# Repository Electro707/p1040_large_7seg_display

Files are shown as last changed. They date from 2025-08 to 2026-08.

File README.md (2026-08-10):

# P1040 - Large 7-Segment Display Driver
\> PCBs (both), Rev 1
\> Firmware, WIP
\> Enclosure, WIP

This project is a driver for some large 4in 7-segment displays

Image of project

# Directory Structure
- `CAD`: All FreeCAD enclosure related stuff
    - C1045: Display Holder
    - C1046: Driver Board Holder, spans 2 displays
    - C1047: Single Display Backside
    - C1048: Dowel
- E1041: PCB, Driver board, KiCAD
- E1042: PCB, Pin to Connector Adapter, KiCAD
- F1043: A demo quick firmware for testing
- F1044: Main Firmware
- `misc`: Miscellaneous files. Right now only the spreadsheet I used for some calculations exists
- `release`: Latest exported build files, includes Schematic, BOM, Gerber, and STL files

# Known Issues
> [!IMPORTANT]
> Please read the file linked below before attempting to build this hardware.

Known issues, and any workarounds, are documented in [ERRATA.md](ERRATA.md)

# Firmware
For more info on the firmware, including building and programming, see [F1044/README.md](F1044/README.md)

# License
This project is licensed under [GPLv3](LICENSE.md)**

** This excludes the files in `E1041 - PCB, Driver Board/ExternalStep`, as they came from the manufacturer.
** Also excludes the files `zones.c` and `zones.h` in `F1044`, as those are modified from the [micro_tz_d library](https://github.com/jdlambert/micro_tz_db/tree/master) which is under an MIT license

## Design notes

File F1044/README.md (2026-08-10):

# F1044 Firmware

## Building
This firmware uses PlatformIO for it's build system.

You should be able to build either in VSCode, or in the CLI by running
```bash
pio run     # to build
pio run --target upload     # to upload
```

## Uploading
During the initial build, one must upload the firmware over the programming interface
on the E1041 PCB, J23 (next to the MCU). The pogo pins is for a [Tag-Connect](https://www.tag-connect.com/product/tc2030-idc-nl)
connector. The programming pinout is available on the schematic.

I personally used a generic ESP programmer dev board to upload the firmware, the one below is what I have.
Image of programmer

On that particular programmer, I connected the yellow header to the tag-connect it as follows:
|---------------|-----------------|
|ESP Programmer | Tag Connect Pin |
|---------------|-----------------|
|RX             |1                |
|TX             |2                |
|3V3            |3                |
|RST            |4                |
|IO0            |5                |
|GND            |6                |
|---------------|-----------------|

Then you can use esptool.py to upload the firmware.

After the initial firmware upload, while you can still use the tag-connect, the firmware also accepts new firmware
over the serial line. I build a python script [`tools/upload.py`](tools/upload.py) to accomplish this.

The first argument is the firmware bin file, the second is either an IP address or the serial port to upload over.

The uploading in PIO is setup to use that script. You can change the port used in [platformio.ini](platformio.ini).

> TODO: Have the config use the port given in VSCode.
> TODO: Have a seperate config that uses esptool to upload, same build settings

## Extra Documentation
The documentation for this project, mainly pertaining to the commands, is written in AsciiDoc, and uses Asciidoctor to generate a PDF or HTML page.

The docs can be built with:
```bash
asciidoctor "doc/F1044 Doc.adoc"        # for HTML
asciidoctor-pdf "doc/F1044 Doc.adoc"    # for PDF
```

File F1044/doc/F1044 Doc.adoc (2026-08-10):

= F1044 - Large 7-Seg Display Firmware
rev 1-dev

== Purpose
The purpose of this document is to describe the F1044 firmware's function and command set

== Functional Description
The F1044 firmware controls up to 8 7-segment displays. The displays are intended to be 4" displays.

NOTE: While the firmware can handle up to 8 displays as per hardware, it has only been tested for 6 displays, although
there is no reason it shouldn't work with 8.

=== Modes
This firmware has the following run-time modes:

* *off* : The displays are disabled, nothing is displayed
* *numb* : Shows a static number on the display. Useful for host updated numeric display
* *time*: Shows the current time based off the timezone set.

The default timezone is EDT (mine!), but can be changed with the `set timeZone` command

=== Time Format

When displaying time, this firmware can present that in the following modes:

* *24hr*: Displays the time as HH:MM in 24-hour format
* *12hr*: Displays the time as HH:MM in 12-hour format. No AM/PM indicator can be shown in this mode
* *metric*: Displays the time as HH:MM in metric format. See https://metric-time.com/ for more information on this format

=== NVM
This firmware stores some parameters in non-volatile memory (nvm). The esp32-arduino's `EEPROM` is used, handling data storage and integrity.
The following table describes what is stored.

[%autowidth]
|===
|Offset|Length|Type|Description

|0
|1
|byte
|NVM magic to check if something is written. Should be 0x5A

|1
|32
|str
|WIFI SSID to connect to

|33
|32
|str
|WIFI password to connect to

|===

=== Communication
This firmware is communicated with over the following interfaces:

* Serial over USB, 115200 baud, 8N1
* Ethernet or WiFi, telnet, port 23
* Ethernet or WiFi, ModBus, port 502 (IN PROGRESS)

All command frames sent to/from the device over serial or Telnet are in ASCII text mode, with either carriage-return (\r) or line-feed (\n) ending per frame.

If a command doesn't sent back a return value, an acknowledgment (ACK) may be sent back as the string "ok".
Any non-acknowledgments (NACK) may be sent as "error: X", where X is a human description of the error.

==== Ethernet, Telnet
This firmware handles being connected over Telnet directly, allowing to connect to this firmware over the built-in `telnet` command on many UNIX systems.

The following telnet commands (different than the commands on the firmware) are handled:

* DO
* WILL
* Interrupt Process, including waiting for timing-mark to responds with a new line and flush the internal receive buffer

This firmware also implements a "exit" command to close a Telnet connection.

[page-layout=landscape]
<<<

== Commands
The commands are structured as verb-noun system; the verb dictates the action, and noun is what to apply the verb to. For example "get mode" requests to "get" the "mode".
The verb and noun are space delimited. Any argument(s) to the command are also space delimited.

The following table list all the commands:

// [%autowidth]
[cols="1,2,5,5,6"]
|===
|Verb|Noun|Arguments|Return|Desc

|ping
|
|
|pong!
|ping-pong!

.8+|set
|mode
|[str], mode
|ACK
|Set the new mode, which is the same string as described in <<Modes>>

|n
|The number to display to in "numb" mode
|ACK, only if in "numb" mode
|

|timeFormat
a|[str], The new time format, either:

- '24hr'
- '12hr'
- 'metric'
|
|Sets the displayed time format, which is the same string as described in <<Time Format>>

|wifiSSID
|SSID
|
|Sets the WiFi SSID

|wifiPass
|password
|
|Sets the WiFi password

|wifiOff
|
|
|Turns wifi on if disabled and not running

|wifiOn
|password
|
|Turns wifi off if enabled and running

|timeZone
|The timezone as a TZ string. Use the command "get allTimeZones" to get valid timezones
|
|

.7+|get
|version
|
|The firmware version
|

|mode
|
|The current mode
|

|n
|
|The current displayed number
|

|timeFormat
|
|The time format
|See <<Time Format>>

|ip
|
|The current IP address of either Ethernet or Wifi, or "none" if not connected to the internet
|

|wifiInfo
|
|The current WiFi SSID and Password set
|

|allTimeZones
|
|All valid time zones
|

.4+|update
|begin
|The firmware size in bytes
|
|Starts a firmware update

|cont
|The number of bytes to send, then the raw bytes after reception of the first ACK
|ACK, followed by another ACK after raw bytes received
|When this command is received with the number of bytes to send, an ACK is sent. The firmware then expects
 that many bytes (not ASCII) to be received, in which another ACK will be sent after all expected bytes are received

|end
|
|
|Finishes the firmware update process

|cancel
|
|
|Cancels any on-going firmware update process

|saveNvm
|
|
|
|Saves the current NVM configuration

|exit
|
|
|
|In Telnet mode, this command sends the required Telnet commands to disconnect.

|reboot
|
|
|
|Reboots the microcontroller
|===

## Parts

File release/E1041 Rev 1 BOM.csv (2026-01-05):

Qty | DNP | Reference | Part Number | Description | Value | Footprint
1 |  | AE1 | 2450AT43F0100001E | Chip Antenna, 2.4Ghz | Antenna_Chip | RF_Antenna:Johanson_2450AT43F0100
4 |  | C1,C21,C22,C23 |  | Capacitor, 0.1uF, 0805 | 0.1u | Capacitor_SMD:C_0805_2012Metric
1 |  | C2 | 865060845002 | Capacitor, 10uF, 100V | 100uF | Capacitor_SMD:C_Elec_6.3x5.4
10 |  | C3,C5,C7,C8,C10,C13,C14,C15,C26,C29 |  |  | 0.1uF | Capacitor_SMD:C_0805_2012Metric,Capacitor_SMD:C_0805_2012Metric_Pad1.18x1.45mm_HandSolder
6 |  | C4,C16,C17,C18,C20,C28 |  |  | 1uF | Capacitor_SMD:C_0805_2012Metric,Capacitor_SMD:C_0805_2012Metric_Pad1.18x1.45mm_HandSolder,Capacitor_SMD:C_1206_3216Metric_Pad1.33x1.80mm_HandSolder
2 |  | C6,C12 |  |  | 22uF | Capacitor_SMD:C_1206_3216Metric_Pad1.33x1.80mm_HandSolder,Capacitor_SMD:C_Elec_6.3x5.4
2 |  | C9,C11 |  |  | 10uF | Capacitor_SMD:C_0805_2012Metric_Pad1.18x1.45mm_HandSolder,Capacitor_SMD:C_1206_3216Metric_Pad1.33x1.80mm_HandSolder
1 |  | C24 |  |  | 2.2pF | Capacitor_SMD:C_0603_1608Metric
1 |  | C25 |  |  | 4pF | Capacitor_SMD:C_0603_1608Metric
1 |  | C27 |  |  | 4.7uF | Capacitor_SMD:C_0805_2012Metric_Pad1.18x1.45mm_HandSolder
2 |  | D1,D2 | CDBHM220L |  | CDBHM220L | Package_TO_SOT_SMD:TO-269AA
1 |  | D3 | SMAJ58A |  | SMAJ58A | Diode_SMD:D_SMA
1 |  | D4 | SMF15A |  | SMF15A | Diode_SMD:D_SMF
2 |  | D5,D6 |  |  | LED | LED_SMD:LED_1206_3216Metric
4 |  | D7,D9,D10,D11 | MBR0530 |  | MBR0530 | Diode_SMD:D_SOD-123
2 |  | F1,F2 | 0ZCJ0050FF2G |  | 500mA | Fuse:Fuse_1206_3216Metric
1 |  | J1 | PJ-202A |  | Barrel_Jack | Connector_BarrelJack:BarrelJack_Horizontal
1 |  | J2 | 1751248 |  | Screw_Terminal_01x02 | TerminalBlock_Phoenix:TerminalBlock_Phoenix_MKDS-1,5-2-5.08_1x02_P5.08mm_Horizontal
1 |  | J3 | 74984104400 |  | 74984104400 | ProjectFootprints:74984104400
1 |  | J4 |  |  | Conn_Coaxial | Connector_Coaxial:SMA_Amphenol_901-143_Horizontal
1 |  | J5 |  |  | Conn_01x03 | Connector_PinSocket_2.54mm:PinSocket_1x03_P2.54mm_Vertical
1 |  | J6 | USB4105-GF-A |  | USB_C_Receptacle_USB2.0_14P | Connector_USB:USB_C_Receptacle_GCT_USB4105-xx-A_16P_TopMnt_Horizontal
16 |  | J7,J8,J9,J10,J11,J12,J13,J14,J15,J16,J17,J18,J19,J20,J21,J22 | B5B-PH-K-S |  | Conn_01x05_Pin | Connector_JST:JST_PH_B5B-PH-K_1x05_P2.00mm_Vertical
1 |  | J23 |  |  | Conn_01x06_Female | Connector:Tag-Connect_TC2030-IDC-NL_2x03_P1.27mm_Vertical
1 |  | JP1 |  | Resistor Jumper, 0805 | Jumper_2_Bridged | Resistor_SMD:R_0805_2012Metric
3 |  | L1,L3,L4 | BLM21AG102SN1D | Ferrite Bead | L_Ferrite | Inductor_SMD:L_0805_2012Metric
1 |  | L2 | MAMK2520T3R3M | Inductor, 3.3uH, 1206 | 3.3uH | Inductor_SMD:L_1206_3216Metric_Pad1.22x1.90mm_HandSolder
1 |  | L5 | L-14C2N2SV4T | Inductor, 2.2nH, 0603 | 2.2nH | Inductor_SMD:L_0603_1608Metric
1 |  | L6 | 1239AS-H-6R8M=P2 | Inductor, 6.8uH, 1206 | 6.8uH | Inductor_SMD:L_1206_3216Metric_Pad1.22x1.90mm_HandSolder
1 |  | Q1 | MMBT3904 | NPN Transistor, SOT23 | MMBT3904 | Package_TO_SOT_SMD:SOT-23
1 |  | R1 |  | Resistor, 13k, 0805 | 13k | Resistor_SMD:R_0805_2012Metric
1 |  | R2 |  | Resistor, 12k, 0805 | 12k | Resistor_SMD:R_0805_2012Metric
1 |  | R3 |  | Resistor, 1.3k, 0805 | 1.3k | Resistor_SMD:R_0805_2012Metric
18 |  | R4,R7,R25,R26,R27,R36,R37,R38,R39,R40,R41,R42,R45,R46,R51,R52,R53,R54 |  | Resistor Jumper, 0805 | 0 | Resistor_SMD:R_0603_1608Metric,Resistor_SMD:R_0805_2012Metric
1 |  | R5 |  |  | 63.4 | Resistor_SMD:R_0805_2012Metric
1 |  | R6 |  |  | 249 | Resistor_SMD:R_0805_2012Metric
1 |  | R8 |  |  | 49.9k | Resistor_SMD:R_0805_2012Metric
3 | DNP | R9,R17,R33 |  |  | 0 | Resistor_SMD:R_0805_2012Metric
1 | DNP | R10 |  |  | DNP | Resistor_SMD:R_0805_2012Metric
1 |  | R11 |  |  | 470 | Resistor_SMD:R_0603_1608Metric_Pad0.98x0.95mm_HandSolder
9 |  | R12,R13,R23,R28,R29,R30,R48,R49,R50 |  |  | 10k | Resistor_SMD:R_0805_2012Metric,Resistor_SMD:R_0805_2012Metric_Pad1.20x1.40mm_HandSolder
1 |  | R14 |  |  | 31.6k | Resistor_SMD:R_0805_2012Metric_Pad1.20x1.40mm_HandSolder
5 |  | R15,R16,R24,R31,R32 |  |  | 1k | Resistor_SMD:R_0805_2012Metric,Resistor_SMD:R_0805_2012Metric_Pad1.20x1.40mm_HandSolder
4 |  | R18,R19,R20,R21 |  |  | 49.9 | Resistor_SMD:R_0805_2012Metric
1 |  | R22 |  |  | 12.1k | Resistor_SMD:R_0805_2012Metric
2 |  | R34,R35 |  |  | 5.1k | Resistor_SMD:R_0805_2012Metric
1 |  | R43 |  |  | 330 | Resistor_SMD:R_0805_2012Metric
1 |  | R44 |  |  | R | Resistor_SMD:R_0805_2012Metric
1 |  | R47 |  |  | 80.6k | Resistor_SMD:R_0805_2012Metric_Pad1.20x1.40mm_HandSolder
1 |  | U1 | TPS2372 |  | TPS2372 | ProjectFootprints:TI_RGW0020B
1 |  | U3 | AP62200WU-7 |  | AP62200WU-7 | Package_TO_SOT_SMD:TSOT-23-6
1 |  | U4 | LAN8720A |  | LAN8720A | Package_DFN_QFN:VQFN-24-1EP_4x4mm_P0.5mm_EP2.5x2.5mm_ThermalVias
1 |  | U5 | ESP32-PICO-D4 |  | ESP32-PICO-D4 | Package_DFN_QFN:QFN-48-1EP_7x7mm_P0.5mm_EP5.3x5.3mm
1 |  | U6 | CH340N |  | CH340N | Package_SO:SOP-8_3.9x4.9mm_P1.27mm
1 |  | U7 | STP08DP05 |  | STP08DP05 | Package_SO:SO-16_3.9x9.9mm_P1.27mm
1 |  | U8 | TBD62783A |  | TBD62783A | Package_SO:SOP-18_7x12.5mm_P1.27mm
1 |  | U9 | 74HC595 |  | 74HC595 | Package_SO:SO-16_3.9x9.9mm_P1.27mm
1 |  | U10 | TPS61040DBV |  | TPS61040DBV | Package_TO_SOT_SMD:SOT-23-5
1 |  | U11 | VCB4812SO-3WR3 |  | VCB48_SO-3WR3 | ProjectFootprints:VCB48_SO-3WR3
1 |  | X1 | ECS-2520MV-250-CN-TR |  | ECS-2520MV-xxx-xx | Oscillator:Oscillator_SMD_ECS_2520MV-xxx-xx-4Pin_2.5x2.0mm

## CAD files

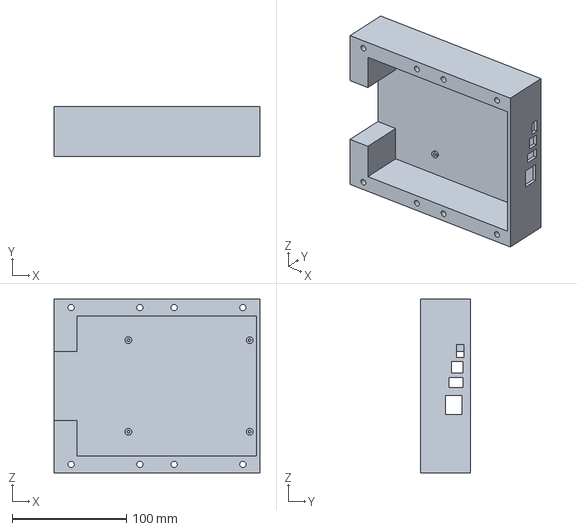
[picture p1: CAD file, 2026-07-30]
CAD/C1046.FCStd
180.0 x 44.0 x 152.0 mm

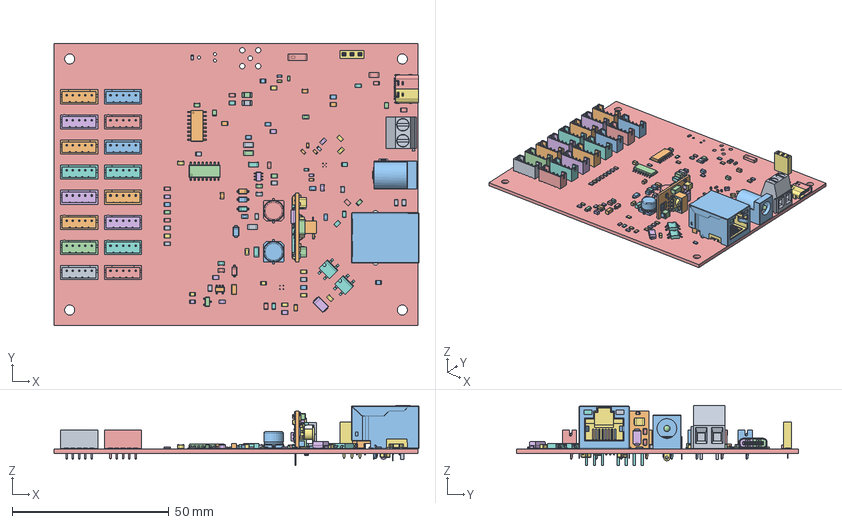
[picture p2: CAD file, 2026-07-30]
CAD/E1041 Rev 1.FCStd
116.3 x 90.0 x 19.2 mm
R_0805_2012Metric
JST_PH_B5B-PH-K_1x05_P2.00mm_Vertical
C_0603_1608Metric
C_0805_2012Metric
C_0805_2012Metric001
R_0805_2012Metric001
PinSocket_1x03_P2.54mm_Vertical
R_0805_2012Metric002
R_0805_2012Metric003
SOT-23-5
C_0805_2012Metric002
R_0805_2012Metric004
R_0805_2012Metric005
JST_PH_B5B-PH-K_1x05_P2.00mm_Vertical001
R_0805_2012Metric006
JST_PH_B5B-PH-K_1x05_P2.00mm_Vertical002
Fuse_1206_3216Metric
JST_PH_B5B-PH-K_1x05_P2.00mm_Vertical003
D_SOD-123
C_0805_2012Metric003
R_0805_2012Metric007
C_0805_2012Metric004
C_0805_2012Metric005
TO-269AA
C_1206_3216Metric
E1041 1.26.1
E1041 1.26.002
E1041 1.26.003
E1041 1.26.004
E1041 1.26.005
E1041 1.26.006
E1041 1.26.007
E1041 1.26.008
E1041 1.26.009
E1041 1.26.010
E1041 1.26.011
E1041 1.26.012
E1041 1.26.013
E1041 1.26.014
E1041 1.26.015
E1041 1.26.016
E1041 1.26.017
E1041 1.26.018
E1041 1.26.019
E1041 1.26.020
E1041 1.26.021
E1041 1.26.022
E1041 1.26.023
E1041 1.26.024
E1041 1.26.025
E1041 1.26.026
E1041 1.26.027
E1041 1.26.028
E1041 1.26.029
E1041 1.26.030
E1041 1.26.031
E1041 1.26.032
E1041 1.26.033
E1041 1.26.034
E1041 1.26.035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

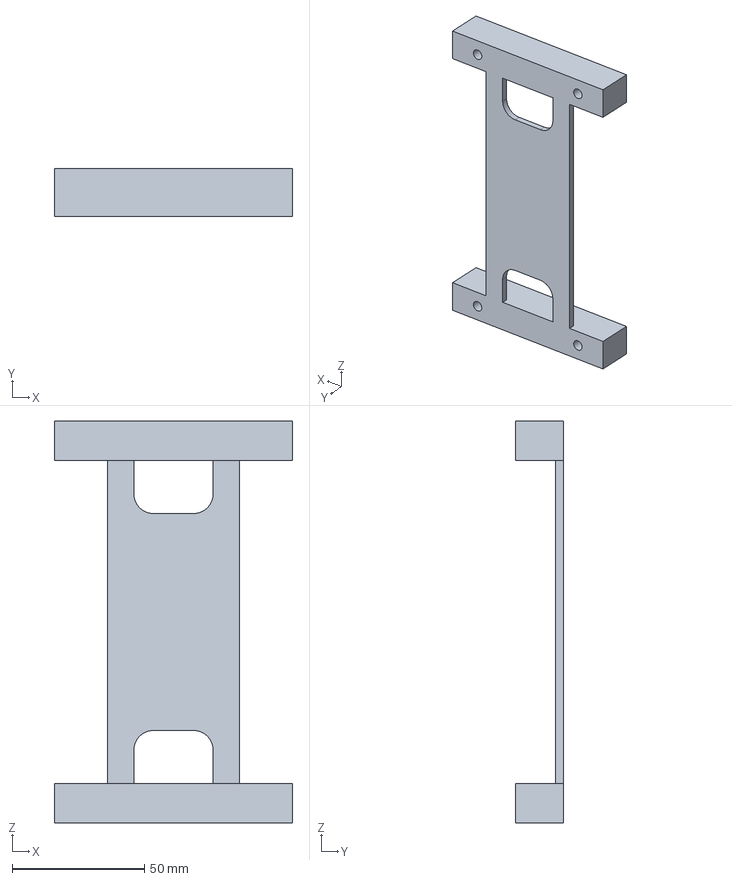
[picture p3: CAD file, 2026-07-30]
CAD/C1045.FCStd
90.0 x 18.0 x 152.0 mm

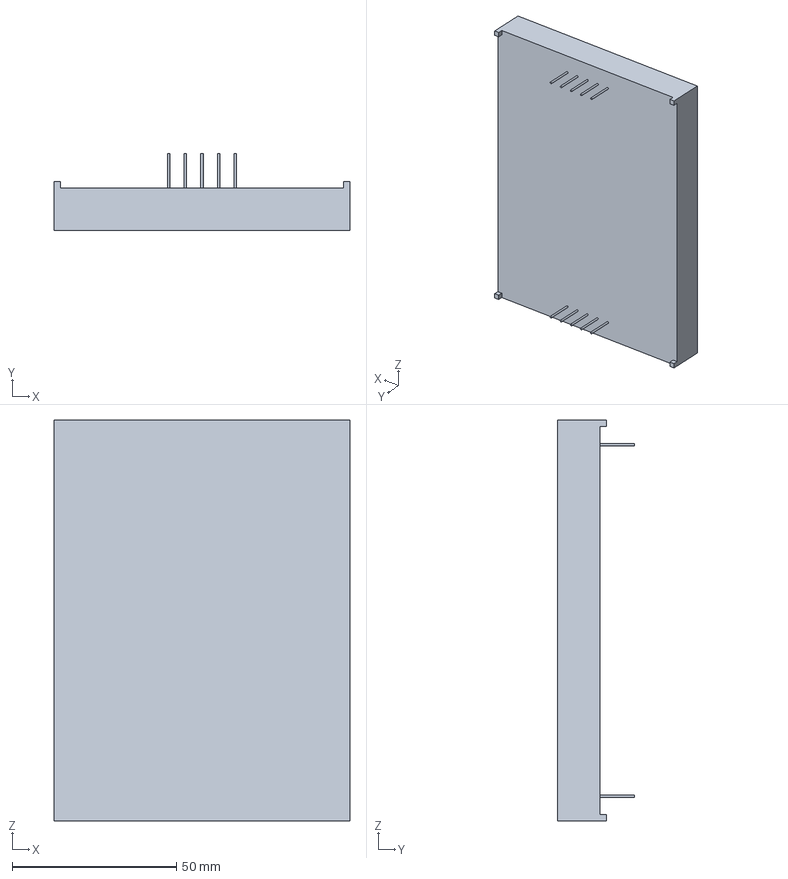
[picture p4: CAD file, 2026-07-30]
CAD/DisplaySingle.FCStd
90.0 x 23.5 x 122.0 mm

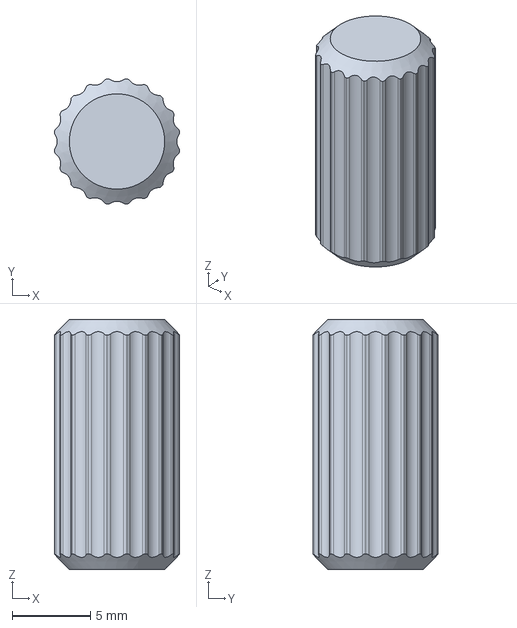
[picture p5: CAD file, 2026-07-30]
CAD/C1048.FCStd
8.01 x 8.01 x 16.0 mm

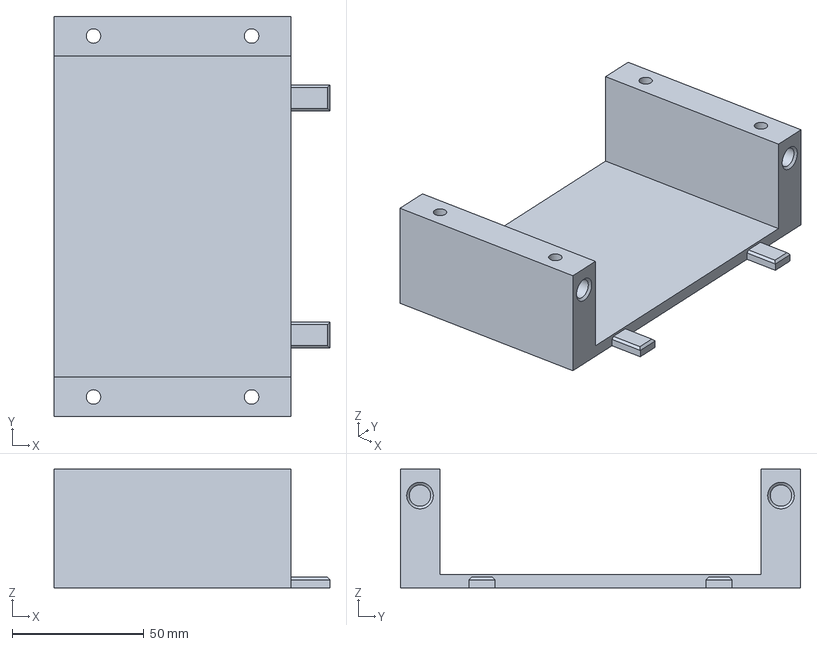
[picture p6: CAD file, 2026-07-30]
CAD/C1047.FCStd
104.8 x 152.0 x 45.0 mm

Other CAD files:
CAD/Assy.FCStd

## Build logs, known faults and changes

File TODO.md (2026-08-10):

# TODO

This is a TODO list for the next PCB revision

- Fix everything in errata
- Add reset button
- Add jumper or button to be able to jump to download mode
- Add test points
    - Some extra debug pads
    - For VCC and 12V as headers (for easy debugging, especially 5v for powerKit)
- Have it so SMA footprint comes out the back or top of enclosure (preferably the top)
- Shorten antenna routing to ensure less than 0.1 lambda of 2.4Gh
- [OPTIONAL] See if one can improve routing for ethernet portion to allow for 100M connection, right now limited to 10M, without going to 4 layer PCB
- Use the CH340 option with reset broken out to allow USB to reset ESP32, useful for uploading firmware as well
- Reduce resistance of dot segment, currently are too dim

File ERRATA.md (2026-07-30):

# Purpose
This document describes the hardware erratas and any potential fix using said hardware.

# E1041 Rev 1: Driver Board

## Errata 1: Crystal Enable
This issue is caused by a pull-up resistor on the enable line, which should be set as a pull-down to disable the crystal unless explicitly enabled by the MCU.

### Fix
For X1, have the pull-up resistor only soldered to the left pad (looking at the board up), then wire a short jumper between it and the nearby pad of the bypass capacitor to tie it to GND. See below:

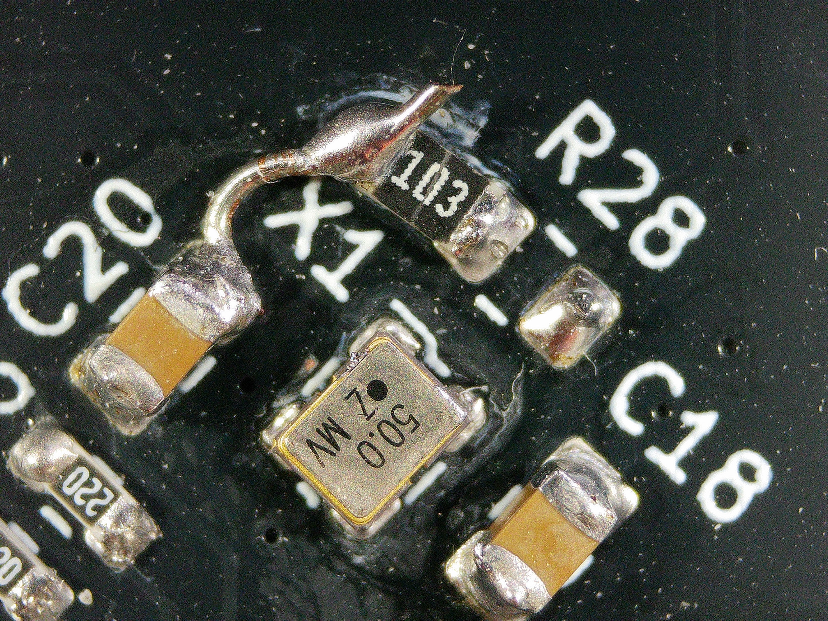
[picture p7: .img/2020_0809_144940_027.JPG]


## Errata 2: 50Mhz clock going to programming line
This issue is caused by GPIO0, which is both one of the programming lines and the 50Mhz Ethernet clock, being broken out to the programming header, which can cause signal integrity issue

### Fix
Either or both:
- Add a 1Kohm resistor in series between the programming line and GPIO0, as shown below
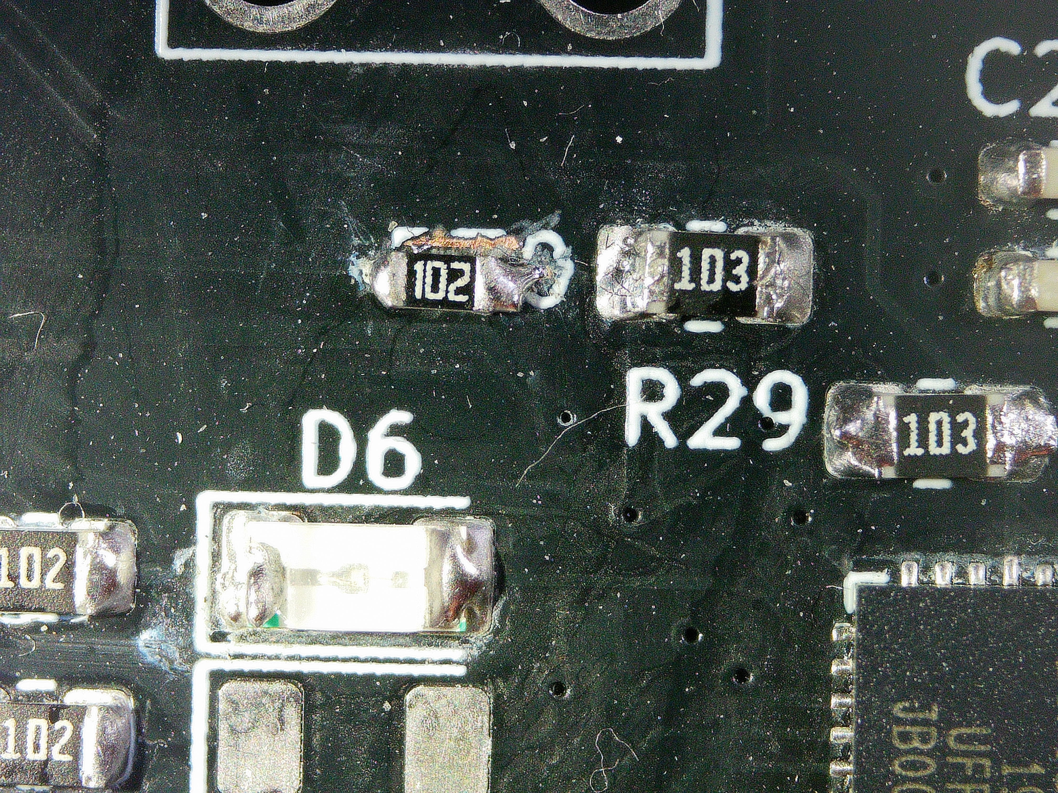
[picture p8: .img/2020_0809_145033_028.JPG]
    - 
- Remove the programming connector as soon as you are finished programming. Even with the previous fix, there is still enough signal integrity issue

## Errata 3: 100M Ethernet Connection Issue
The Ethernet Phy fails to establish a connection with the ESP32 when running in the default 10/100M mode in esp32's ethernet library.
This is presumably caused by bad signal integrity due to 2-layer design, among other factors.

### Fix
In software reducing the Ethernet to 10M only seems to fix this.

## Errata 4: Supplying with only 5v over USB

When only USB power is supplied, the device periodically restarts

### Investigation Notes
- When proving 5v on USB, there is a spike on the uS scale to ~1v. This tells me this is getting loaded down somehow
- It is random when, from power on, the device restarts. Sometimes instant, sometimes several seconds before the next restart. This tells me I am operating right on the edge of failure/working
- When supplying the 12V barrel jack with 12V, I don't see a USB dropout issue. This tells me the 5/12v to 3.3v converter is OK, most likely problem is the 12V generation
- Suspecting it might be something to do with the 5v to 12v boost converter section

### Fix
Root cause awaiting, TODO

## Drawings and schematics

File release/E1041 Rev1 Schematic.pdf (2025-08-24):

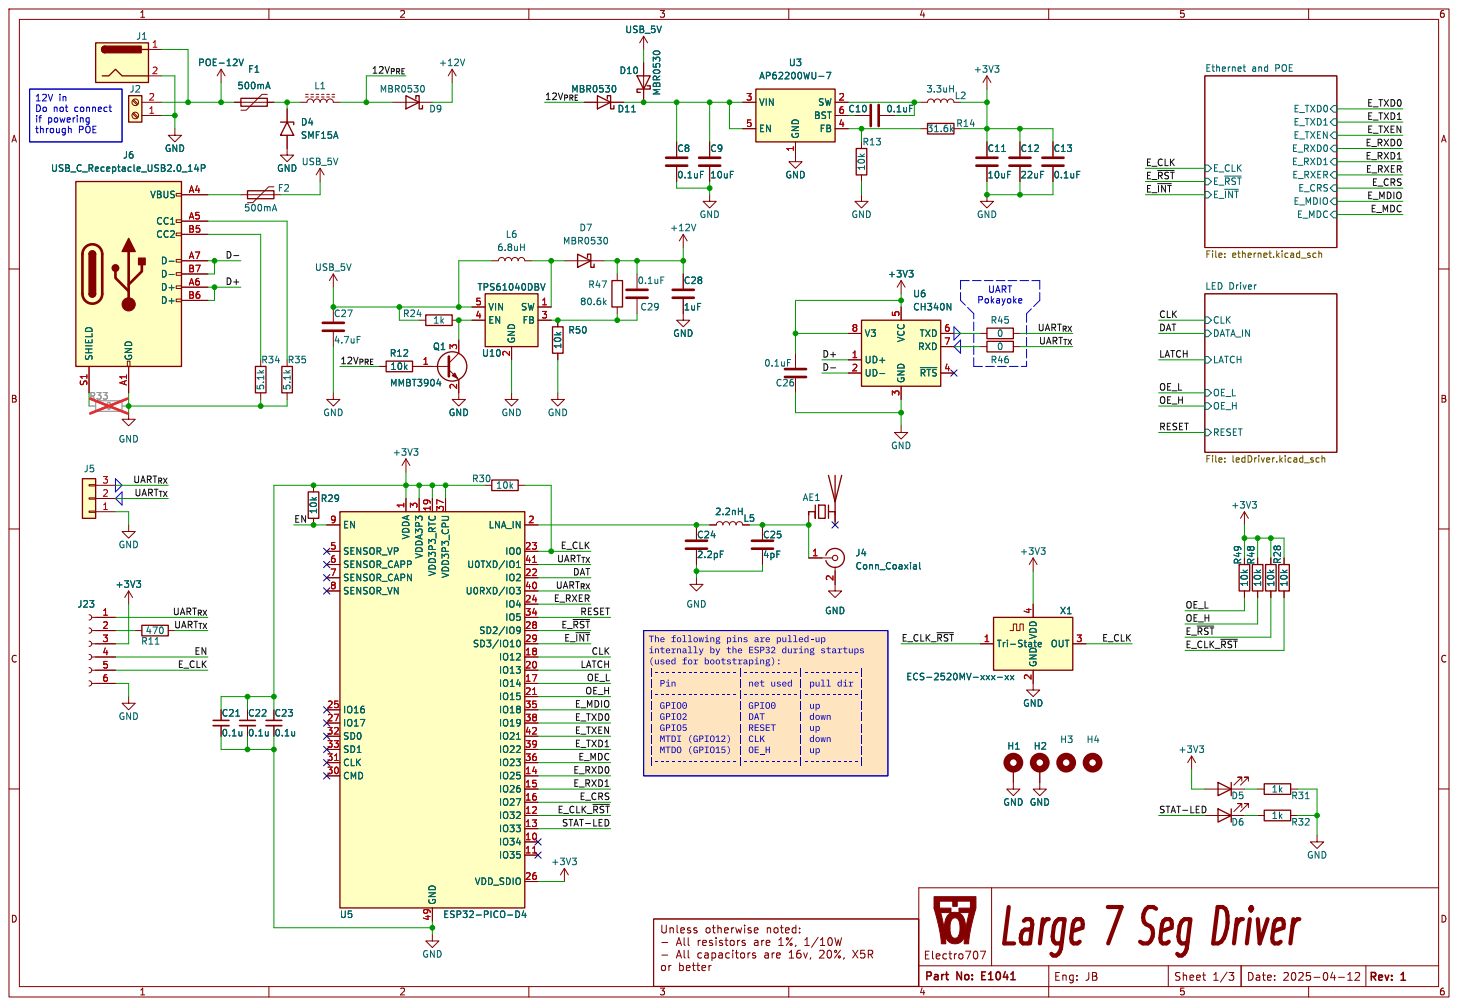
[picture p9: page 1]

12V in Do not connect

1 SW 2 BST 6 FB 4 GND GND

2 OUT 3 X1 ECS-2520MV-xxx-xx H3

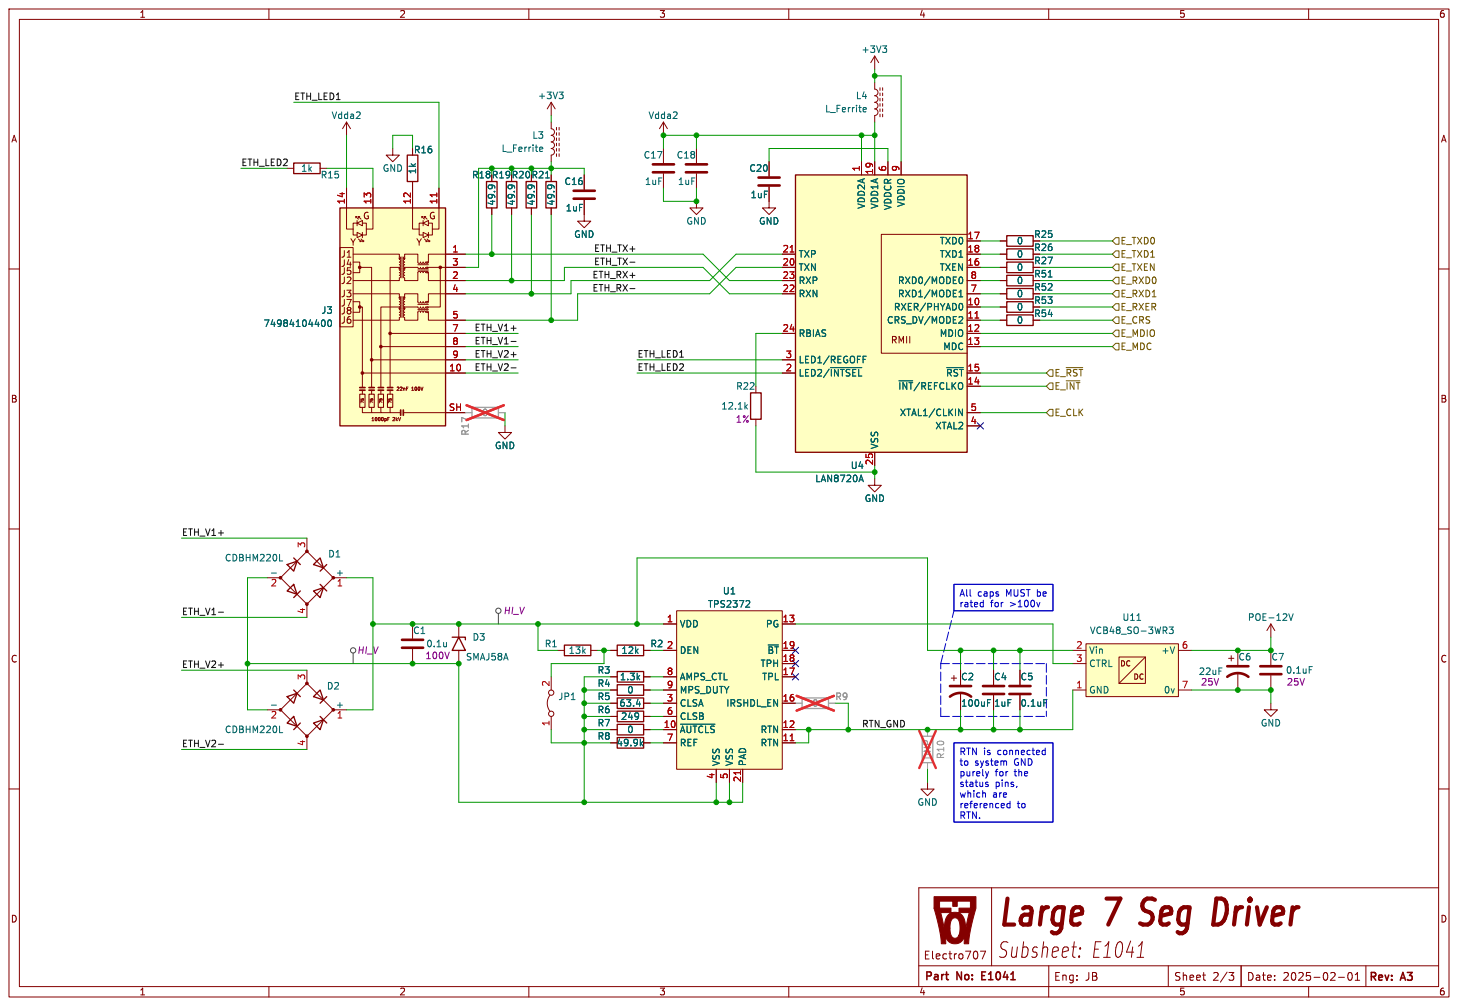
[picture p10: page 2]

1 TXP 21 TXN 20 RXP 23 RXN 22 RBIAS 24

5 PAD 21 PG 13 ~{BT} 19 TPH 18 TPL 17

to system GND
purely for the
status pins, which are

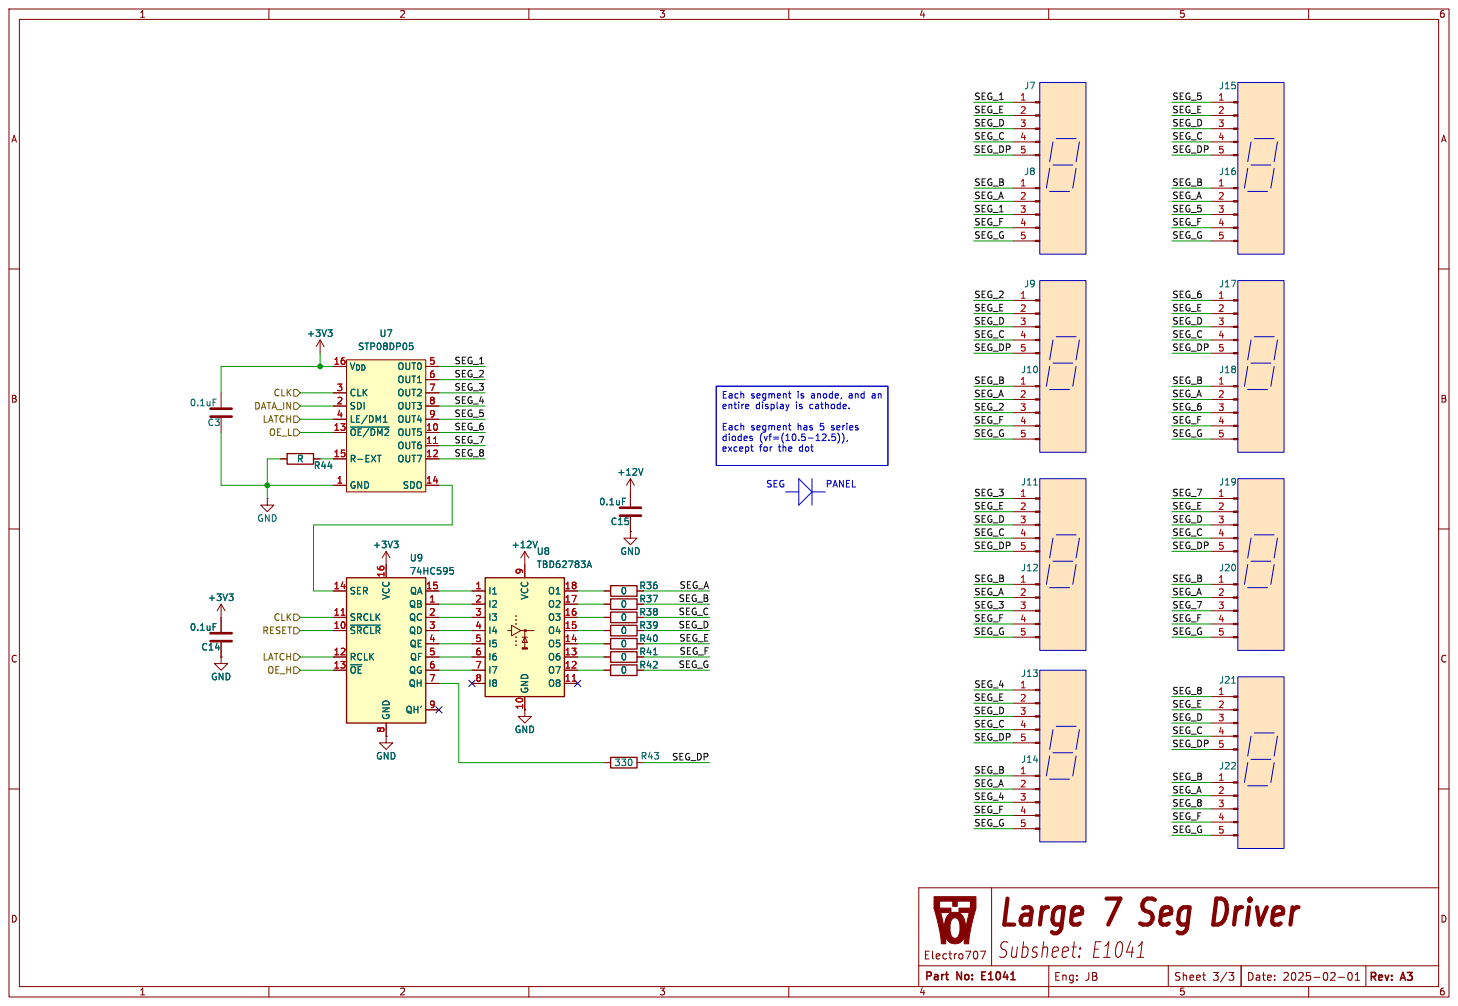
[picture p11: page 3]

Each segment is anode, and an

8 QA 15 QB 1 QC 2 QD 3 QE 4 QF 5 QG 6 QH 7 QH' 9 +3V3 +3V3 GND

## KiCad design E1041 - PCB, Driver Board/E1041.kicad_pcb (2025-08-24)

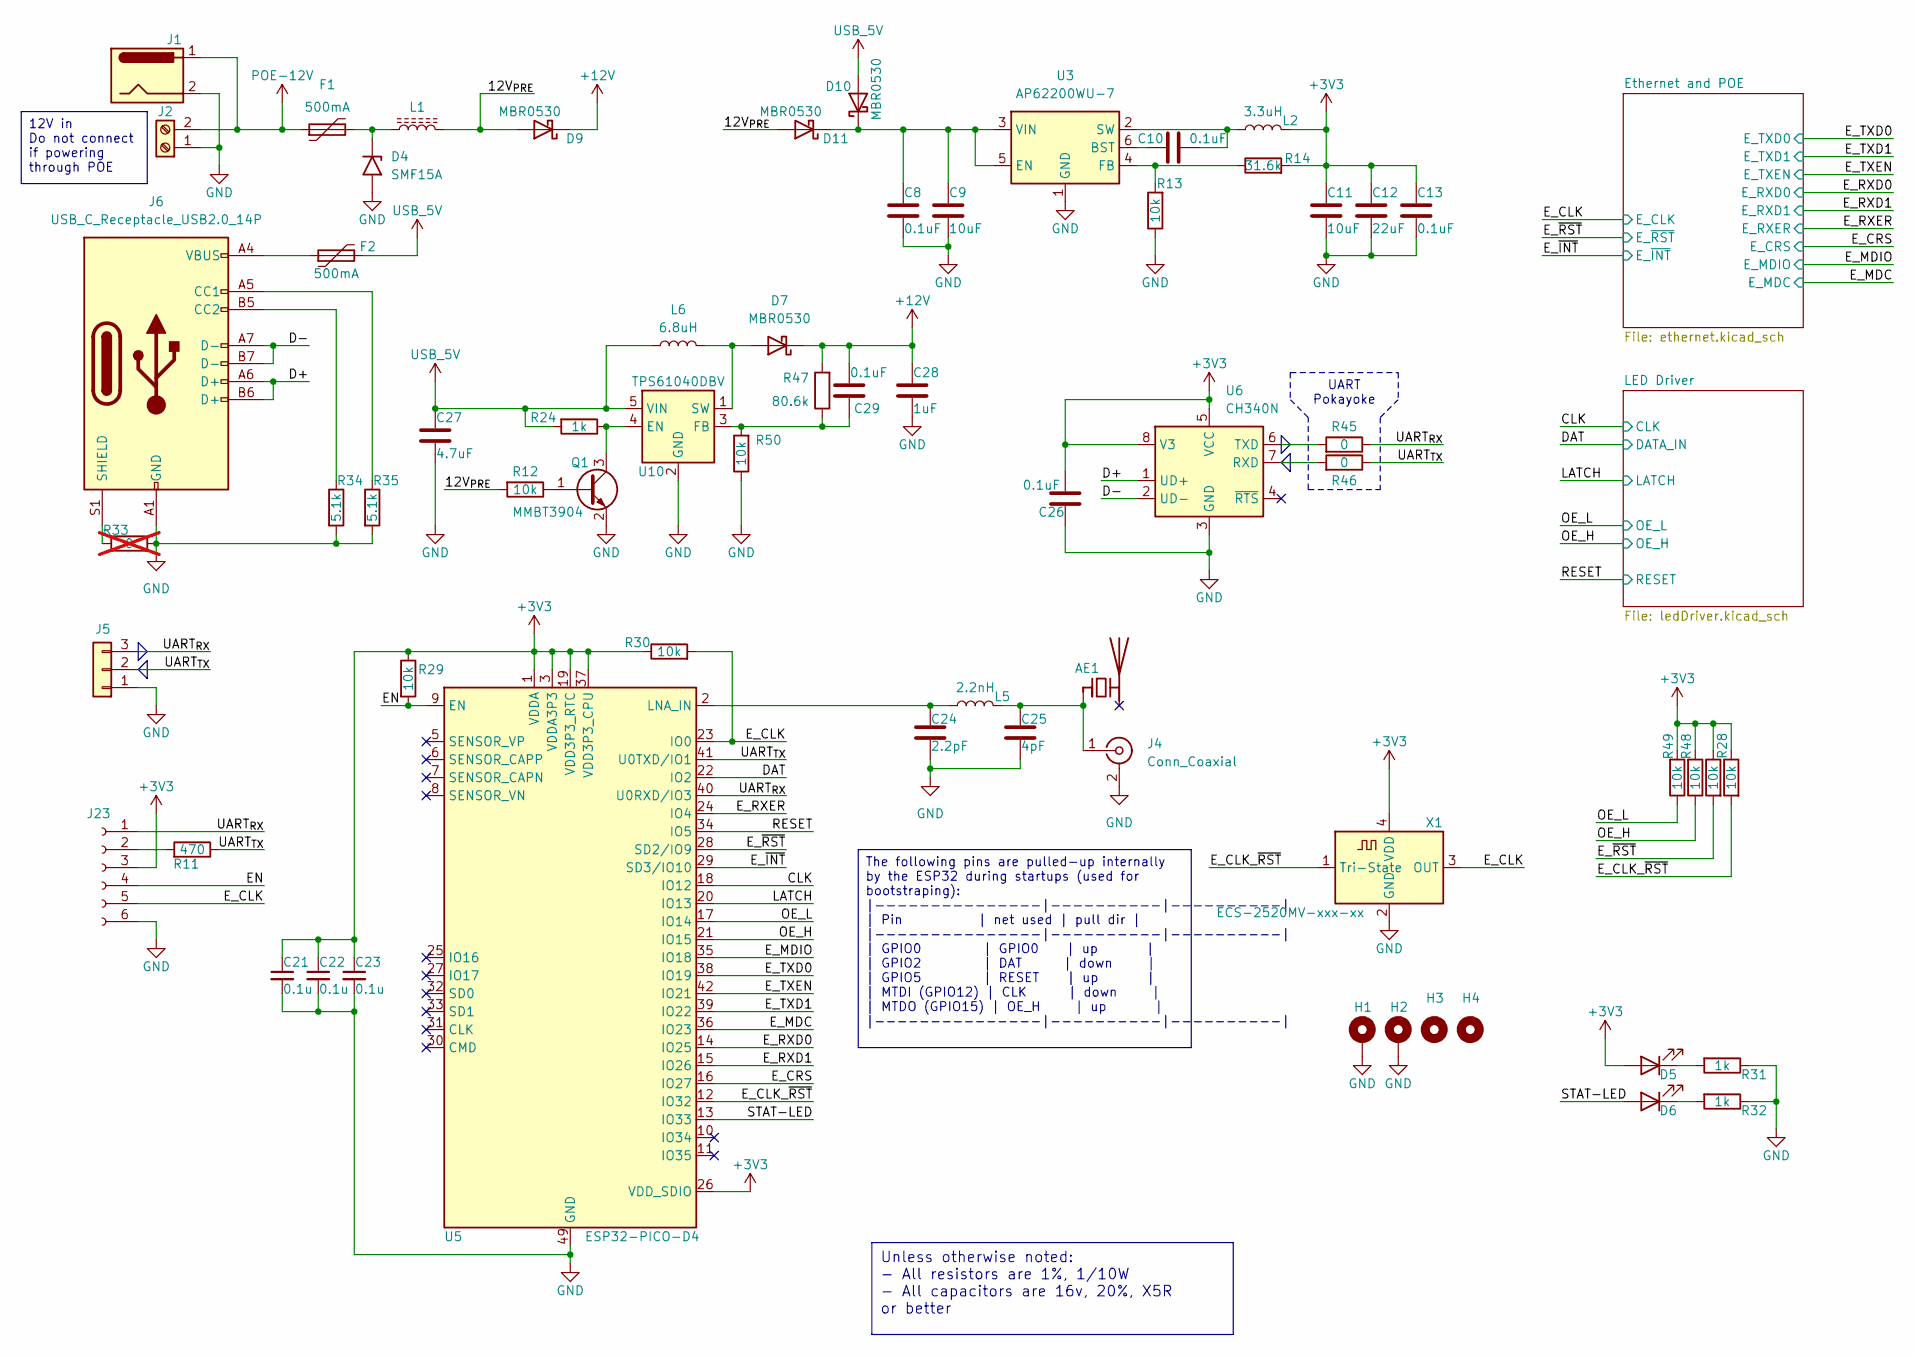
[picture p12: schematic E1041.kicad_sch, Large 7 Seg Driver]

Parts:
AE1: Antenna_Chip; Johanson_2450AT43F0100
C8, C10: 0.1uF; C_0805_2012Metric_Pad1.18x1.45mm_HandSolder
C9: 10uF; C_0805_2012Metric_Pad1.18x1.45mm_HandSolder
C11: 10uF; C_1206_3216Metric_Pad1.33x1.80mm_HandSolder
C12: 22uF; C_1206_3216Metric_Pad1.33x1.80mm_HandSolder
C13, C26, C29: 0.1uF; C_0805_2012Metric
C21, C22, C23: 0.1u; C_0805_2012Metric
C24: 2.2pF; C_0603_1608Metric
C25: 4pF; C_0603_1608Metric
C27: 4.7uF; C_0805_2012Metric_Pad1.18x1.45mm_HandSolder
C28: 1uF; C_0805_2012Metric_Pad1.18x1.45mm_HandSolder
D4: SMF15A; D_SMF
D5, D6: LED; LED_1206_3216Metric
D7, D9, D10, D11: MBR0530; D_SOD-123
F1, F2: 500mA; Fuse_1206_3216Metric
H1, H2: MountingHole_Pad; MountingHole_3.2mm_M3_DIN965_Pad
H3, H4: MountingHole_Pad; MountingHole_3.2mm_M3_DIN965
J1: Barrel_Jack; BarrelJack_Horizontal
J2: Screw_Terminal_01x02; TerminalBlock_Phoenix_MKDS-1,5-2-5.08_1x02_P5.08mm_Horizont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
J4: Conn_Coaxial; SMA_Amphenol_901-143_Horizontal
J5: Conn_01x03; PinSocket_1x03_P2.54mm_Vertical
J6: USB_C_Receptacle_USB2.0_14P; USB_C_Receptacle_GCT_USB4105-xx-A_16P_TopMnt_Horizontal
J23: Conn_01x06_Female; Tag-Connect_TC2030-IDC-NL_2x03_P1.27mm_Vertical
L1: L_Ferrite; L_0805_2012Metric
L2: 3.3uH; L_1206_3216Metric_Pad1.22x1.90mm_HandSolder
L5: 2.2nH; L_0603_1608Metric
L6: 6.8uH; L_1206_3216Metric_Pad1.22x1.90mm_HandSolder
Q1: MMBT3904; SOT-23
R11: 470; R_0603_1608Metric_Pad0.98x0.95mm_HandSolder
R12, R13, R29, R30, R50: 10k; R_0805_2012Metric_Pad1.20x1.40mm_HandSolder
R14: 31.6k; R_0805_2012Metric_Pad1.20x1.40mm_HandSolder
R23, R28, R48, R49: 10k; R_0805_2012Metric
R24: 1k; R_0805_2012Metric_Pad1.20x1.40mm_HandSolder
R31, R32: 1k; R_0805_2012Metric
R33: 0; R_0805_2012Metric; not fitted
R34, R35: 5.1k; R_0805_2012Metric
R45, R46: 0; R_0805_2012Metric
R47: 80.6k; R_0805_2012Metric_Pad1.20x1.40mm_HandSolder
U3: AP62200WU-7; TSOT-23-6
U5: ESP32-PICO-D4; QFN-48-1EP_7x7mm_P0.5mm_EP5.3x5.3mm
U6: CH340N; SOP-8_3.9x4.9mm_P1.27mm
U10: TPS61040DBV; SOT-23-5
X1: ECS-2520MV-xxx-xx; Oscillator_SMD_ECS_2520MV-xxx-xx-4Pin_2.5x2.0mm

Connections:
+3V3: C11.1, C12.1, C13.1, C21.1, C22.1, C23.1, C26.2, D5.2 (A), J23.3, L2.2, R14.2, R23.1, R28.1, R29.1, R30.1, R48.2, R49.2, U5.1 (VDDA), U5.3 (VDDA3P3), U5.4 (VDDA3P3), U5.19 (VDD3P3_RTC), U5.26 (VDD_SDIO), U5.37 (VDD3P3_CPU), U5.43 (VDDA), U5.46 (VDDA), U6.5 (VCC), U6.8 (V3), X1.4 (VDD); also elsewhere on the board
+12V: C28.1, C29.2, D7.1 (K), D9.1 (K), R47.2; also elsewhere on the board
/12V_{PRE}: D9.2 (A), D11.2 (A), L1.2, R12.2
/CLK: U5.18 (IO12); also elsewhere on the board
/D+: J6.A6 (D+), J6.B6 (D+), U6.1 (UD+)
/D-: J6.A7 (D-), J6.B7 (D-), U6.2 (UD-)
/DAT: U5.22 (IO2); also elsewhere on the board
/EN: J23.4, R29.2, U5.9 (EN)
/E_CLK: J23.5, R30.2, U5.23 (IO0), X1.3 (OUT); also elsewhere on the board
/E_CLK_~RST: R28.2, U5.12 (IO32), X1.1 (Tri-State)
/E_CRS: U5.16 (IO27); also elsewhere on the board
/E_MDC: U5.36 (IO23); also elsewhere on the board
/E_MDIO: U5.35 (IO18); also elsewhere on the board
/E_RXD0: U5.14 (IO25); also elsewhere on the board
/E_RXD1: U5.15 (IO26); also elsewhere on the board
/E_RXER: U5.24 (IO4); also elsewhere on the board
/E_TXD0: U5.38 (IO19); also elsewhere on the board
/E_TXD1: U5.39 (IO22); also elsewhere on the board
/E_TXEN: U5.42 (IO21); also elsewhere on the board
/E_~INT: U5.29 (SD3/IO10); also elsewhere on the board
/E_~RST: R23.2, U5.28 (SD2/IO9); also elsewhere on the board
/LATCH: U5.20 (IO13); also elsewhere on the board
/OE_H: R48.1, U5.21 (IO15); also elsewhere on the board
/OE_L: R49.1, U5.17 (IO14); also elsewhere on the board
/RESET: U5.34 (IO5); also elsewhere on the board
/STAT-LED: D6.2 (A), U5.13 (IO33)
/UART_{RX}: J5.3, J23.1, R45.1, U5.40 (U0RXD/IO3)
/UART_{TX}: J5.2, R11.1, R46.1, U5.41 (U0TXD/IO1)
GND: C8.2, C9.2, C11.2, C12.2, C13.2, C21.2, C22.2, C23.2, C24.2, C25.2, C26.1, C27.2, C28.2, D4.2 (A2), H1.1, H2.1, J1.2, J2.1, J4.2 (Ext), J5.1, J6.A1 (GND), J6.A12 (GND), J6.B1 (GND), J6.B12 (GND), J23.6, Q1.2 (E), R13.1, R31.1, R32.1, R33.2, R34.2, R35.2, R50.1, U3.1 (GND), U5.49 (GND), U6.3 (GND), U10.2 (GND), X1.2 (GND); also elsewhere on the board
unnamed: AE1.1 (FEED), C25.1, J4.1 (In), L5.2
unnamed: D4.1 (A1), F1.2, L1.1
unnamed: D5.1 (K), R31.2
unnamed: D6.1 (K), R32.2
unnamed: D7.2 (A), L6.2, U10.1 (SW)
unnamed: C8.1, C9.1, D10.1 (K), D11.1 (K), U3.3 (VIN), U3.5 (EN)
unnamed: F2.1, J6.A4 (VBUS), J6.A9 (VBUS), J6.B4 (VBUS), J6.B9 (VBUS)
unnamed: J6.A5 (CC1), R35.1
unnamed: J6.B5 (CC2), R34.1
unnamed: J6.S1 (SHIELD), R33.1
unnamed: J23.2, R11.2
unnamed: Q1.1 (B), R12.1
unnamed: Q1.3 (C), R24.1, U10.4 (EN)
unnamed: C10.1, U3.6 (BST)
unnamed: R13.2, R14.1, U3.4 (FB)
unnamed: C10.2, L2.1, U3.2 (SW)
unnamed: C24.1, L5.1, U5.2 (LNA_IN)
unnamed: R46.2, U6.7 (RXD)
unnamed: R45.2, U6.6 (TXD)
unnamed: C29.1, R47.1, R50.2, U10.3 (FB)
POE-12V: F1.1, J1.1, J2.2; also elsewhere on the board
USB_5V: C27.1, D10.2 (A), F2.2, L6.1, R24.2, U10.5 (VIN)

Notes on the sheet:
The following pins are pulled-up internally by the ESP32 during startups (used for bootstraping): |---------------|----------|----------| | Pin | net used | pull dir | |---------------|----------|----------| | GPIO0 | GPIO0 | up | | GPIO2 | DAT | down | | GPIO5 | RESET | up | | MTDI (GPIO12) | CLK 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
UART Pokayoke
12V in Do not connect if powering through POE
Unless otherwise noted: - All resistors are 1%, 1/10W - All capacitors are 16v, 20%, X5R or better

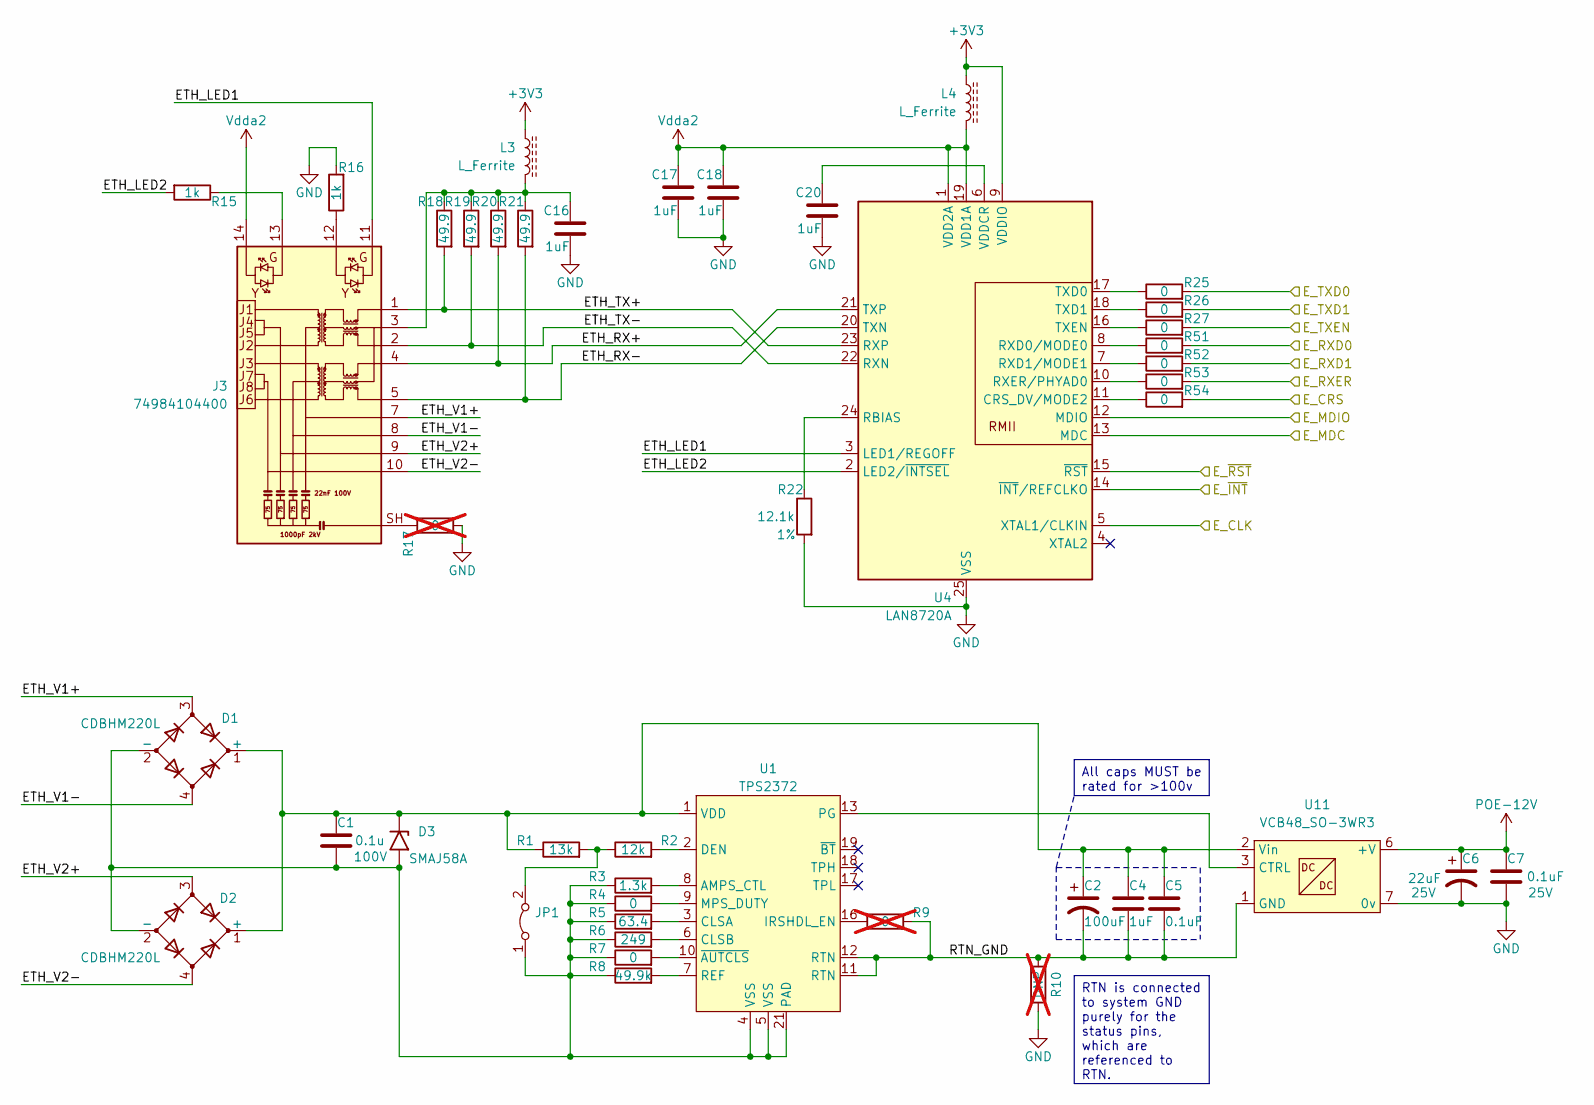
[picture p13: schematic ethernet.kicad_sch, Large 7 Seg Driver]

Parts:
C1: 0.1u; C_0805_2012Metric; Voltage 100V
C2: 100uF; C_Elec_6.3x5.4
C4: 1uF; C_1206_3216Metric_Pad1.33x1.80mm_HandSolder
C5: 0.1uF; C_0805_2012Metric
C6: 22uF; C_Elec_6.3x5.4; Voltage 25V
C7: 0.1uF; C_0805_2012Metric; Voltage 25V
C16, C17, C18, C20: 1uF; C_0805_2012Metric
D1, D2: CDBHM220L; TO-269AA
D3: SMAJ58A; D_SMA
J3: 74984104400
JP1: Jumper_2_Bridged; R_0805_2012Metric
L3, L4: L_Ferrite; L_0805_2012Metric
R1: 13k; R_0805_2012Metric
R2: 12k; R_0805_2012Metric
R3: 1.3k; R_0805_2012Metric
R4, R7: 0; R_0805_2012Metric
R5: 63.4; R_0805_2012Metric
R6: 249; R_0805_2012Metric
R8: 49.9k; R_0805_2012Metric
R9, R17: 0; R_0805_2012Metric; not fitted
R10: DNP; R_0805_2012Metric; not fitted
R15, R16: 1k; R_0805_2012Metric
R18, R19, R20, R21: 49.9; R_0805_2012Metric
R22: 12.1k; R_0805_2012Metric
R25, R26, R27, R51, R52, R53, R54: 0; R_0603_1608Metric
U1: TPS2372; TI_RGW0020B
U4: LAN8720A; VQFN-24-1EP_4x4mm_P0.5mm_EP2.5x2.5mm_ThermalVias
U11: VCB48_SO-3WR3

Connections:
+3V3: L3.2, L4.2, U4.9 (VDDIO); also elsewhere on the board
/E_CLK: U4.5 (XTAL1/CLKIN); also elsewhere on the board
/E_CRS: R54.2; also elsewhere on the board
/E_MDC: U4.13 (MDC); also elsewhere on the board
/E_MDIO: U4.12 (MDIO); also elsewhere on the board
/E_RXD0: R51.2; also elsewhere on the board
/E_RXD1: R52.2; also elsewhere on the board
/E_RXER: R53.2; also elsewhere on the board
/E_TXD0: R25.2; also elsewhere on the board
/E_TXD1: R26.2; also elsewhere on the board
/E_TXEN: R27.2; also elsewhere on the board
/E_~INT: U4.14 (~INT/REFCLKO); also elsewhere on the board
/E_~RST: U4.15 (~RST); also elsewhere on the board
/Ethernet and POE/ETH_LED1: J3.11, U4.3 (LED1/REGOFF)
/Ethernet and POE/ETH_LED2: R15.2, U4.2 (LED2/~INTSEL)
/Ethernet and POE/ETH_RX+: J3.4 (RD+), R20.2, U4.21 (TXP)
/Ethernet and POE/ETH_RX-: J3.5 (RD-), R21.2, U4.20 (TXN)
/Ethernet and POE/ETH_TX+: J3.1 (TD+), R18.2, U4.23 (RXP)
/Ethernet and POE/ETH_TX-: J3.2 (TD-), R19.2, U4.22 (RXN)
/Ethernet and POE/ETH_V1+: D1.3, J3.7 (V1+)
/Ethernet and POE/ETH_V1-: D1.4, J3.8 (V1-)
/Ethernet and POE/ETH_V2+: D2.3, J3.9 (V2+)
/Ethernet and POE/ETH_V2-: D2.4, J3.10 (V2-)
/Ethernet and POE/RTN_GND: C2.2, C4.2, C5.2, R9.2, R10.2, U1.11 (RTN), U1.12 (RTN), U11.1 (GND)
GND: C6.2, C7.2, C16.2, C17.2, C18.2, C20.2, R10.1, R16.2, R17.2, R22.2, U4.25 (VSS), U11.7 (0v); also elsewhere on the board
unnamed: C1.1, C2.1, C4.1, C5.1, D1.1 (+), D2.1 (+), D3.1 (A1), R1.1, U1.1 (VDD), U11.2 (Vin)
unnamed: C1.2, D1.2 (-), D2.2 (-), D3.2 (A2), JP1.1 (A), R3.1, R4.1, R5.1, R6.1, R7.1, R8.1, U1.4 (VSS), U1.5 (VSS), U1.21 (PAD)
unnamed: C16.1, J3.3 (CD), L3.1, R18.1, R19.1, R20.1, R21.1
unnamed: J3.12, R16.1
unnamed: J3.13, R15.1
unnamed: J3.SH, R17.1
unnamed: JP1.2 (B), R1.2, R2.1
unnamed: R3.2, U1.8 (AMPS_CTL)
unnamed: R5.2, U1.3 (CLSA)
unnamed: R6.2, U1.6 (CLSB)
unnamed: R2.2, U1.2 (DEN)
unnamed: R9.1, U1.16 (IRSHDL_EN)
unnamed: R4.2, U1.9 (MPS_DUTY)
unnamed: U1.13 (PG), U11.3 (CTRL)
unnamed: R8.2, U1.7 (REF)
unnamed: R7.2, U1.10 (~AUTCLS)
unnamed: R54.1, U4.11 (CRS_DV/MODE2)
unnamed: R22.1, U4.24 (RBIAS)
unnamed: R51.1, U4.8 (RXD0/MODE0)
unnamed: R52.1, U4.7 (RXD1/MODE1)
unnamed: R53.1, U4.10 (RXER/PHYAD0)
unnamed: R25.1, U4.17 (TXD0)
unnamed: R26.1, U4.18 (TXD1)
unnamed: R27.1, U4.16 (TXEN)
unnamed: C20.1, U4.6 (VDDCR)
POE-12V: C6.1, C7.1, U11.6 (+V); also elsewhere on the board
Vdda2: C17.1, C18.1, J3.14, L4.1, U4.1 (VDD2A), U4.19 (VDD1A)

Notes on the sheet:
RTN is connected to system GND purely for the status pins, which are referenced to RTN.
All caps MUST be rated for >100v

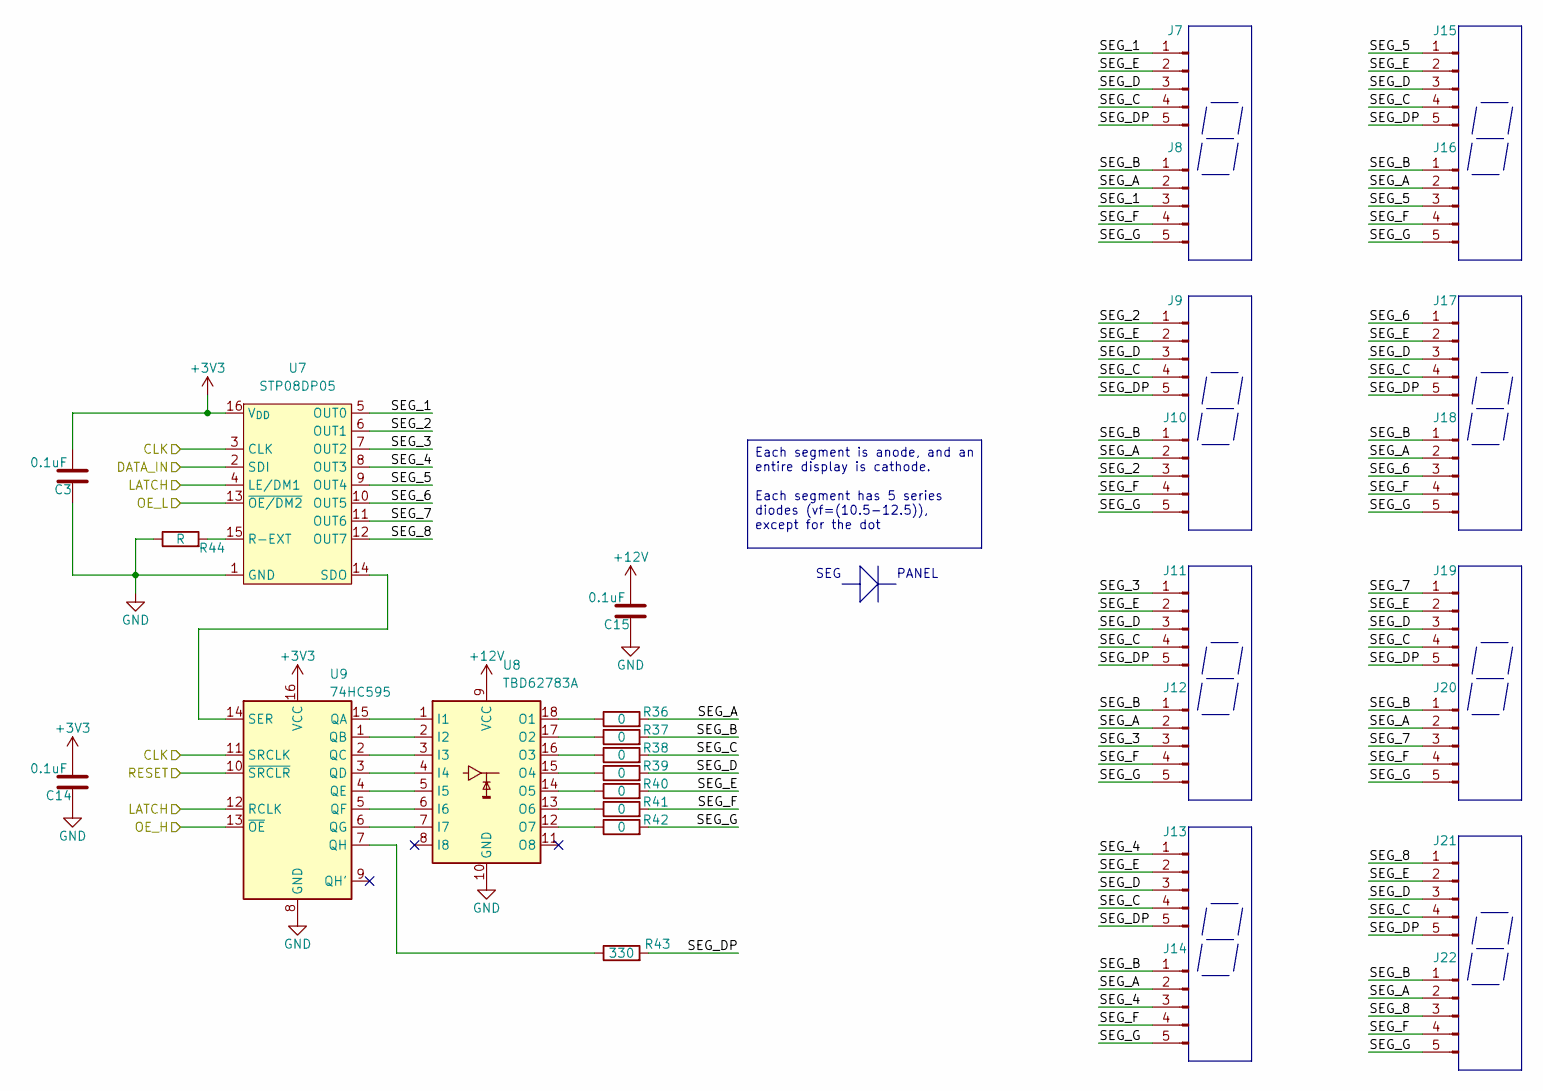
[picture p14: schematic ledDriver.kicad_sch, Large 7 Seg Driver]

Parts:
C3, C14, C15: 0.1uF; C_0805_2012Metric
J7, J8, J9, J10, J11, J12, J13, J14, J15, J16, J17, J18, J19, J20, J21, J22: Conn_01x05_Pin; JST_PH_B5B-PH-K_1x05_P2.00mm_Vertical
R36, R37, R38, R39, R40, R41, R42: 0; R_0805_2012Metric
R43: 330; R_0805_2012Metric
R44: R; R_0805_2012Metric
U7: STP08DP05; SO-16_3.9x9.9mm_P1.27mm
U8: TBD62783A; SOP-18_7x12.5mm_P1.27mm
U9: 74HC595; SO-16_3.9x9.9mm_P1.27mm

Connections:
+3V3: C3.2, C14.2, U7.16 (V_{DD}), U9.16 (VCC); also elsewhere on the board
+12V: C15.2, U8.9 (VCC); also elsewhere on the board
/CLK: U7.3 (CLK), U9.11 (SRCLK); also elsewhere on the board
/DAT: U7.2 (SDI); also elsewhere on the board
/LATCH: U7.4 (LE/DM1), U9.12 (RCLK); also elsewhere on the board
/LED Driver/SEG_1: J7.1, J8.3, U7.5 (OUT0)
/LED Driver/SEG_2: J9.1, J10.3, U7.6 (OUT1)
/LED Driver/SEG_3: J11.1, J12.3, U7.7 (OUT2)
/LED Driver/SEG_4: J13.1, J14.3, U7.8 (OUT3)
/LED Driver/SEG_5: J15.1, J16.3, U7.9 (OUT4)
/LED Driver/SEG_6: J17.1, J18.3, U7.10 (OUT5)
/LED Driver/SEG_7: J19.1, J20.3, U7.11 (OUT6)
/LED Driver/SEG_8: J21.1, J22.3, U7.12 (OUT7)
/LED Driver/SEG_A: J8.2, J10.2, J12.2, J14.2, J16.2, J18.2, J20.2, J22.2, R36.2
/LED Driver/SEG_B: J8.1, J10.1, J12.1, J14.1, J16.1, J18.1, J20.1, J22.1, R37.2
/LED Driver/SEG_C: J7.4, J9.4, J11.4, J13.4, J15.4, J17.4, J19.4, J21.4, R38.2
/LED Driver/SEG_D: J7.3, J9.3, J11.3, J13.3, J15.3, J17.3, J19.3, J21.3, R39.2
/LED Driver/SEG_DP: J7.5, J9.5, J11.5, J13.5, J15.5, J17.5, J19.5, J21.5, R43.2
/LED Driver/SEG_E: J7.2, J9.2, J11.2, J13.2, J15.2, J17.2, J19.2, J21.2, R40.2
/LED Driver/SEG_F: J8.4, J10.4, J12.4, J14.4, J16.4, J18.4, J20.4, J22.4, R41.2
/LED Driver/SEG_G: J8.5, J10.5, J12.5, J14.5, J16.5, J18.5, J20.5, J22.5, R42.2
/OE_H: U9.13 (~OE); also elsewhere on the board
/OE_L: U7.13 (~OE/DM2); also elsewhere on the board
/RESET: U9.10 (~SRCLR); also elsewhere on the board
GND: C3.1, C14.1, C15.1, R44.1, U7.1 (GND), U8.10 (GND), U9.8 (GND); also elsewhere on the board
unnamed: R44.2, U7.15 (R-EXT)
unnamed: U7.14 (SDO), U9.14 (SER)
unnamed: U8.1 (I1), U9.15 (QA)
unnamed: U8.2 (I2), U9.1 (QB)
unnamed: U8.3 (I3), U9.2 (QC)
unnamed: U8.4 (I4), U9.3 (QD)
unnamed: U8.5 (I5), U9.4 (QE)
unnamed: U8.6 (I6), U9.5 (QF)
unnamed: U8.7 (I7), U9.6 (QG)
unnamed: R36.1, U8.18 (O1)
unnamed: R37.1, U8.17 (O2)
unnamed: R38.1, U8.16 (O3)
unnamed: R39.1, U8.15 (O4)
unnamed: R40.1, U8.14 (O5)
unnamed: R41.1, U8.13 (O6)
unnamed: R42.1, U8.12 (O7)
unnamed: R43.1, U9.7 (QH)

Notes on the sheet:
SEG
PANEL
Each segment is anode, and an entire display is cathode. Each segment has 5 series diodes (vf=(10.5-12.5)), except for the dot

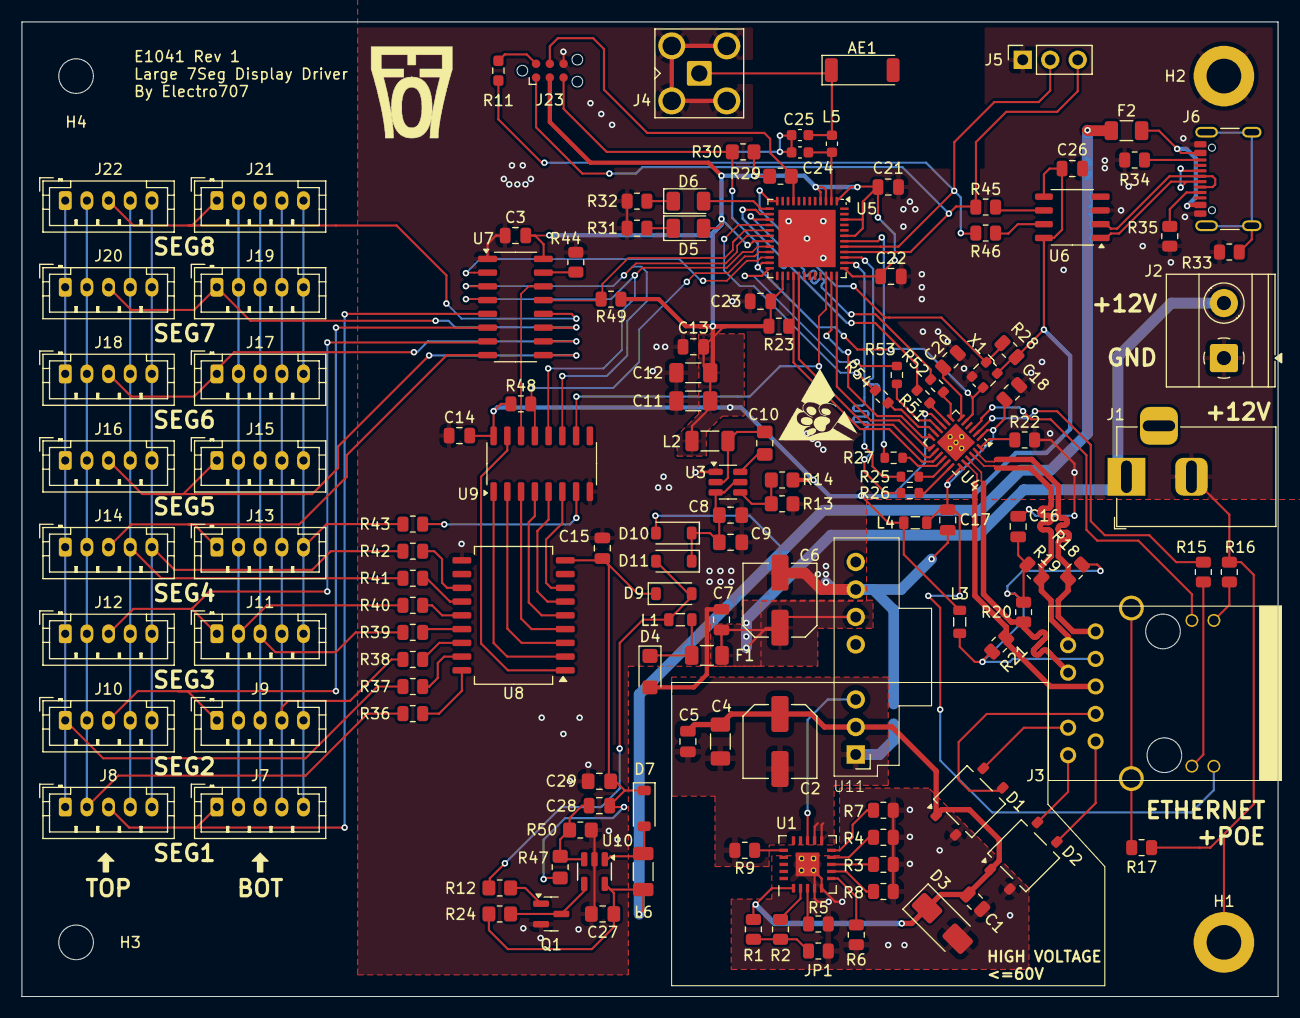
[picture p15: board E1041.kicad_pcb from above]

Board: 2 copper layers, 116.0 x 90.0 mm, 141 parts (1 on the bottom side), 121 nets.

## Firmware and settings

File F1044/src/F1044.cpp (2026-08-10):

/**
 * Large 7-Segment display controller firmware
 * jb, 2025-07-05
 *
 * Some examples used for this application
 * - https://github.com/espressif/arduino-esp32/blob/master/libraries/WiFi/examples/WiFiTelnetToSerial/WiFiTelnetToSerial.ino
 *
 */
#include <Arduino.h>
#include <string.h>
#include <SPI.h>
#include <WiFiClient.h>
#include <Network.h>
#include <ETH.h>
#include <WiFi.h>
#include <EEPROM.h>

#include "common.h"
#include "comms.h"
#include "wifiDefault.h"
#include "modbus.h"
#include "zones.h"

#define UPDATE_NOCRYPT
#include <Update.h>

char wifiSsid[32];
char wifiPassword[32];

const char* ntpServer = "pool.ntp.org";
const long gmtOffset_sec = -5 * 3600;  // Set your timezone offset (e.g., -5*3600 for EST)
const int daylightOffset_sec = 3600;   // Daylight savings (if applicable)
struct tm currTime;

static const int spiClk = 1000000;
SPIClass vspi = SPIClass(VSPI);

hw_timer_t* mainTimer = timerBegin(1000000);

EEPROMClass nvm("main");

static bool eth_connected = false;

// array of the segments enabled per display
// Each bit is the enabled segments for that display
uint8_t segDat[N_DISPLAYS] = { 0 };
// an array of what displays to enable per segment
// Due to the circuit, this is what is actually used in the update ISR
uint8_t dispPerSeg[SEG_PER_DISPLAY] = { 0 };

NetworkServer telnetServer(TELNET_PORT);
NetworkServer modbusServer(MODBUS_PORT);
NetworkClient telnetClient[TELNET_MAX_CLIENTS];  // for now only allow one client
NetworkClient modbusClients[MODBUS_MAX_CLIENTS];

modbusC_s modbusHandlers[MODBUS_MAX_CLIENTS];

uint currDisplayedN = 0;  // the current number being displayed. Only to be updated in displayNumber

mode_e currMode;
timeFormat_e timeFormat;

TimerHandle_t updateTimeT;

bool isWifiEnabled = false;

// parser struct for our custom parser
ParserHandler serialParser;
ParserHandler networkParser;

char fwVersion[FW_VERSION_STR_LEN] = FW_VERSION;

// gets called from onNetworkEvent when we get an IP address, either WiFi or Ethernet
void onNetworkConnected(void){
	configTime(gmtOffset_sec, daylightOffset_sec, ntpServer);
	telnetServer.begin();
	telnetServer.setNoDelay(true);
	modbusServer.begin();
	modbusServer.setNoDelay(true);
}

// gets called from onNetworkEvent when we loose an IP address
void onNetworkClosed(void){
	telnetServer.end();
	modbusServer.end();
}

// WARNING: onEvent is called from a separate FreeRTOS task (thread)!
void onNetworkEvent(arduino_event_id_t event) {
	// todo: clean up the case statements as needed
	// todo: handle if we have wifi connected and ethernet at the same time?
	switch (event) {
		case ARDUINO_EVENT_ETH_START:
			DEBUG("ETH Started");
			// The hostname must be set after the interface is started, but needs
			// to be set before DHCP, so set it from the event handler thread.
			ETH.setHostname("esp32-ethernet");
			break;
		case ARDUINO_EVENT_ETH_CONNECTED:
			DEBUG("ETH Connected");
#ifdef CONNECT_WIFI
            DEBUG("Disconnecting WIFI");
            WiFi.disconnect(true);
#endif
			break;
		case ARDUINO_EVENT_ETH_GOT_IP:
			DEBUG("ETH Got IP %s", ETH.localIP().toString().c_str());
			eth_connected = true;
			onNetworkConnected();
			break;
		case ARDUINO_EVENT_ETH_LOST_IP:
			DEBUG("ETH Lost IP");
			eth_connected = false;
			onNetworkClosed();
			break;
		case ARDUINO_EVENT_ETH_DISCONNECTED:
			DEBUG("ETH Disconnected");
			eth_connected = false;
            // restart WiFi back up
#ifdef CONNECT_WIFI
            DEBUG("Restarting WIFI");
            WiFi.begin(wifiSsid, wifiPassword);
#endif
			break;
		case ARDUINO_EVENT_ETH_STOP:
			DEBUG("ETH Stopped");
			eth_connected = false;
			break;

		case ARDUINO_EVENT_WIFI_OFF:				 DEBUG("Wifi is set to off"); break;
		case ARDUINO_EVENT_WIFI_READY:               DEBUG("WiFi interface ready"); break;
		case ARDUINO_EVENT_WIFI_SCAN_DONE:           DEBUG("Completed scan for access points"); break;
		case ARDUINO_EVENT_WIFI_STA_START:
			DEBUG("WiFi client started");
			isWifiEnabled = true;
			break;
		case ARDUINO_EVENT_WIFI_STA_STOP:
			DEBUG("WiFi client stopped");
			isWifiEnabled = false;
			break;
		case ARDUINO_EVENT_WIFI_STA_CONNECTED:
            DEBUG("Connected to WiFi access point");
            break;
		case ARDUINO_EVENT_WIFI_STA_DISCONNECTED:
            DEBUG("Disconnected from WiFi access point");
            break;
		case ARDUINO_EVENT_WIFI_STA_AUTHMODE_CHANGE: DEBUG("Authentication mode of access point has changed"); break;
		case ARDUINO_EVENT_WIFI_STA_GOT_IP:
			DEBUG("Obtained Wifi IP address: %s", WiFi.localIP().toString().c_str());
			onNetworkConnected();
			break;
		case ARDUINO_EVENT_WIFI_STA_LOST_IP:
			DEBUG("Lost Wifi IP address and IP address is reset to 0");
			onNetworkClosed();
			break;
		case ARDUINO_EVENT_WPS_ER_SUCCESS:          DEBUG("WiFi Protected Setup (WPS): succeeded in enrollee mode"); break;
		case ARDUINO_EVENT_WPS_ER_FAILED:           DEBUG("WiFi Protected Setup (WPS): failed in enrollee mode"); break;
		case ARDUINO_EVENT_WPS_ER_TIMEOUT:          DEBUG("WiFi Protected Setup (WPS): timeout in enrollee mode"); break;
		case ARDUINO_EVENT_WPS_ER_PIN:              DEBUG("WiFi Protected Setup (WPS): pin code in enrollee mode"); break;

		case ARDUINO_EVENT_WIFI_AP_START:           DEBUG("WiFi access point started"); break;
		case ARDUINO_EVENT_WIFI_AP_STOP:            DEBUG("WiFi access point  stopped"); break;
		case ARDUINO_EVENT_WIFI_AP_STACONNECTED:    DEBUG("Client connected"); break;
		case ARDUINO_EVENT_WIFI_AP_STADISCONNECTED: DEBUG("Client disconnected"); break;
		case ARDUINO_EVENT_WIFI_AP_STAIPASSIGNED:   DEBUG("Assigned IP address to client"); break;
		case ARDUINO_EVENT_WIFI_AP_PROBEREQRECVED:  DEBUG("Received probe request"); break;
		case ARDUINO_EVENT_WIFI_AP_GOT_IP6:         DEBUG("AP IPv6 is preferred"); break;
		case ARDUINO_EVENT_WIFI_STA_GOT_IP6:        DEBUG("STA IPv6 is preferred"); break;
		default:                                    DEBUG("Other eth/wifi event: %d", event); break;
	}

	digitalWrite(IO_DEBUG_LED, eth_connected);
}

void nvmSave(void){
    nvm.writeByte(0, NVM_MAGIC);
    nvm.writeBytes(1, wifiSsid, 32);
    nvm.writeBytes(1+32, wifiPassword, 32);
    nvm.commit();
}

void nvmLoad(void){
    // we have an empty nvm, initialize
	if(nvm.read(0) != NVM_MAGIC){
		strcpy(wifiSsid, DEFAULT_WIFI_SSID);
		strcpy(wifiPassword, DEFAULT_WIFI_PASSWORD);
		return;
	}
	nvm.readBytes(1, wifiSsid, 32);
	nvm.readBytes(1+32, wifiPassword, 32);
}

void nvmInit(void){
	if (!nvm.begin(0x200)) {
		// todo: this came from their example. is restarting the best?
		DEBUG("Failed to initialize nvm");
		DEBUG("Restarting...");
		delay(1000);
		ESP.restart();
	}
}

void updateTimeCallback(TimerHandle_t xTimer){
  uint currTimeN = 0;
  uint dots;
  time_t now;
  float tmp;

  // basically doing the same as getLocalTime in `esp32-hal-time.c`, but no timeout. if it fails it fails
//   time(&now);
//   localtime_r(&now, &currTime);
  if (currTime.tm_year > (2016 - 1900)) {
	switch (timeFormat) {
	  case TIME_FORMAT_24HR:
		currTimeN = currTime.tm_sec + (currTime.tm_min * 100) + (currTime.tm_hour * 10000);
		break;
	  case TIME_FORMAT_12HR:
		currTimeN = currTime.tm_sec + (currTime.tm_min * 100) + ((currTime.tm_hour % 12) * 10000);
		break;
	  case TIME_FORMAT_METRIC:
		// get the current time as a proportion of the day
		tmp = currTime.tm_sec + (60.0 * (float)currTime.tm_min) + (3600.0 * (float)currTime.tm_hour);
		tmp /= 86400;
		// now start dividing and filling the hours and minutes spot
		tmp *= 10;
		currTimeN = (uint)floor(tmp);
		tmp -= currTimeN;
		currTimeN *= 100;  // convert the hours to the 100's decimal place
		tmp *= 100;
		currTimeN += (uint)floor(tmp);
		break;
	}

	dots = 0;
	if(currTime.tm_sec & 0b01){
		dots = (1 << 2);
		dots |= (1 << 4);
	}

	displayNumber(currTimeN, dots);

	// debug
	currTime.tm_sec++;
  }
}

// handles the transition in the display mode
void setDisplayMode(mode_e newMode) {
  currMode = newMode;

  if (newMode == DISPLAY_MODE_TIME) {
	xTimerStart(updateTimeT, 0);
  } else {
	xTimerStop(updateTimeT, 0);
  }

  if (newMode == DISPLAY_MODE_OFF) {
	for (int i = 0; i < SEG_PER_DISPLAY; i++) {
	  dispPerSeg[i] = 0;
	}
  }
}

// updates the array used to actually display to the display
void displayUpdate(void){
  for (uint i = 0; i < SEG_PER_DISPLAY; i++) {
	dispPerSeg[i] = 0;
	for (int d = 0; d < N_DISPLAYS; d++) {
	  if (segDat[d] & (1 << i)) {
		dispPerSeg[i] |= 1 << d;
	  }
	}
  }

}

void displayNumber(int n, uint dotBitMap) {
  const uint8_t numberToSeg[10] = { 0x3F, 0x06, 0x5B, 0x4F, 0x66, 0x6D, 0x7D, 0x07, 0x7F, 0x6F };
  const int power10[N_DISPLAYS] = { 1, 10, 100, 1000, 10000, 100000 };

  uint toS;

  for (uint currDisp = 0; currDisp < N_DISPLAYS; currDisp++) {
	toS = n / power10[currDisp];
	toS %= 10;
	segDat[currDisp] = numberToSeg[toS];  // test, segment A only
	if(dotBitMap & (1 << currDisp)){
		segDat[currDisp] |= 1 << 7;
	}
  }
  displayUpdate();
  currDisplayedN = n;  // update global variable
}

// used to only display - for all segment
void displayAllDash(void){
	for (uint d = 0; d < N_DISPLAYS; d++) {
		segDat[d] = 0x40;
	}
	displayUpdate();
}

void realTimeIsr(void) {
	static uint8_t currentSegment = 0;  // the current segment to be displayed
	// static uint8_t currentDisplay = 0;  // the current segment to be displayed

	digitalWrite(IO_SHIFT_OE_CAT, HIGH);
	digitalWrite(IO_SHIFT_OE_ANA, HIGH);

	digitalWrite(IO_SHIFT_LDR, LOW);
	vspi.transfer(1 << currentSegment);
	vspi.transfer(dispPerSeg[currentSegment]);
	delayMicroseconds(10);
	digitalWrite(IO_SHIFT_LDR, HIGH);

	digitalWrite(IO_SHIFT_OE_CAT, LOW);
	digitalWrite(IO_SHIFT_OE_ANA, LOW);

	if(++currentSegment >= SEG_PER_DISPLAY){
		currentSegment = 0;
	}
}

void setup(void) {
	Serial.setRxBufferSize(MAX_FW_BUFFER);
	Serial.begin(115200);
	DEBUG("begin");
	// delay(5000);

	digitalWrite(IO_SHIFT_OE_CAT, HIGH);
	digitalWrite(IO_SHIFT_OE_ANA, HIGH);

	pinMode(IO_SHIFT_OE_CAT, OUTPUT);
	pinMode(IO_SHIFT_OE_ANA, OUTPUT);
	pinMode(IO_SHIFT_LDR, OUTPUT);
	pinMode(IO_SHIFT_RST, OUTPUT);
	pinMode(IO_SHIFT_CLK, OUTPUT);  // todo: does SPI need it? should it be set on it's own
	pinMode(IO_SHIFT_DAT, OUTPUT);
	pinMode(IO_ETH_EN_CLK, OUTPUT);
	pinMode(IO_ETH_RST, OUTPUT);
	pinMode(IO_DEBUG_LED, OUTPUT);

	// todo: for some reason digitalWrite before pinMode doesn't set the IO state. Look into
	digitalWrite(IO_SHIFT_OE_CAT, HIGH);
	digitalWrite(IO_SHIFT_OE_ANA, HIGH);
	digitalWrite(IO_ETH_RST, LOW);

	vspi.begin(IO_SHIFT_CLK, -1, IO_SHIFT_DAT, -1);
	vspi.setHwCs(false);
	vspi.beginTransaction(SPISettings(spiClk, MSBFIRST, SPI_MODE0));

	// reset LED segments on bootup
	digitalWrite(IO_SHIFT_RST, HIGH);
	digitalWrite(IO_SHIFT_LDR, LOW);
	vspi.transfer(0x00);
	vspi.transfer(0x00);
	digitalWrite(IO_SHIFT_LDR, HIGH);
	digitalWrite(IO_SHIFT_OE_CAT, LOW);
	digitalWrite(IO_SHIFT_OE_ANA, LOW);

	// startup NVM read
	nvmInit();
	nvmLoad();

	updateTimeT = xTimerCreate("updateTimeT", pdMS_TO_TICKS(500), true, NULL, updateTimeCallback);

	timeFormat = TIME_FORMAT_24HR;
	// displayAllDash();
	// setDisplayMode(DISPLAY_MODE_TIME);
	displayNumber(88, 0);
	setDisplayMode(DISPLAY_MODE_NUMB);

	// todo: rtos task for this?
	timerAttachInterrupt(mainTimer, &realTimeIsr);
	timerAlarm(mainTimer, 1000, true, 0);  // every 500uS call the real-time interrupt

	for(u8 i=0;i<MODBUS_MAX_CLIENTS;i++){
		modbusHandlers[i].client = &modbusClients[i];
		modbusInit(&modbusHandlers[i]);
	}

	// delay(2000);
	DEBUG("begin ether");
	digitalWrite(IO_ETH_EN_CLK, HIGH);
	delay(50);
	digitalWrite(IO_ETH_RST, HIGH);
	delay(10);

	// delay(1000);
	Network.onEvent(onNetworkEvent);

	// delay(1000);
#ifdef CONNECT_ETHERNET
	ETH.setHostname(NETWORK_HOSTNAME);
	ETH.setAutoNegotiation(false);
	ETH.setLinkSpeed(10);
	ETH.setFullDuplex(true);
	ETH.begin(ETH_PHY_TYPE, ETH_PHY_ADDR, ETH_PHY_MDC, ETH_PHY_MDIO, ETH_PHY_POWER, ETH_CLK_MODE);
#endif
#ifdef CONNECT_WIFI
	WiFi.setHostname(NETWORK_HOSTNAME);
	WiFi.config(INADDR_NONE, INADDR_NONE, INADDR_NONE, INADDR_NONE);
	WiFi.begin(wifiSsid, wifiPassword);
#endif

	serialParser.setPrintClass(&Serial);

	DEBUG("postBegin");
}

// goes through ana array of clients to figure out which one is empty
NetworkClient *getFreeClient(NetworkClient *n, uint32 maxC){
	while(maxC--){
		if(n->connected() == false){
			return n;
		}
		n++;
	}
	return NULL;
}

void loop(void) {
	static uint8_t n = 0;
	NetworkClient *freeClient;
	int32 i;
	// digitalWrite(IO_DEBUG_LED, !digitalRead(IO_DEBUG_LED));

	// handle new client connections
	if (telnetServer.hasClient()) {
		freeClient = getFreeClient(telnetClient, TELNET_MAX_CLIENTS);
		if (freeClient == NULL) {
			// accept the client connection, but immediately disconnect
			DEBUG("Max clients connected, refusing new connection\n");
			telnetServer.accept().stop();
		} else {
			*freeClient = telnetServer.accept();
			networkParser.setPrintClass(freeClient);
			DEBUG("New client: %s", freeClient->remoteIP().toString().c_str());
		}
	}

	// handle new modbus client connections
	if (modbusServer.hasClient()) {
		freeClient = getFreeClient(modbusClients, MODBUS_MAX_CLIENTS);
		if (freeClient == NULL) {
			// accept the client connection, but immediately disconnect
			modbusServer.accept().stop();
		} else {
			*freeClient = modbusServer.accept();
			DEBUG("New modbus client: %s", freeClient->remoteIP().toString().c_str());
		}
	}

	// client read loop
	// todo: hack as we only have 1 client max for telnet
	if (telnetClient[0].connected()) {
		while (telnetClient[0].available()) {
			networkParser.parse(telnetClient[0].read());
		}
	}

	for(i=0;i<MODBUS_MAX_CLIENTS;i++){
		// only process what we have connected
		if(modbusClients[i].connected() == false){
			continue;
		}
		while (modbusClients[i].available()) {
			modbusProcessByte(&modbusHandlers[i], modbusClients[i].read());
		}
	}

	while (Serial.available()) {
		serialParser.parse(Serial.read());
	}
}

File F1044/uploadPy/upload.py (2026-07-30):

"""
A python script to update the F1044 firmware with a given binary file exported from Arduino
"""
import time

import serial
import argparse
from pathlib import Path
import logging
import os
import socket


class InterfaceSer:
    def __init__(self, port):
        self.ser = serial.Serial(port, 115200, timeout=1)

    def write(self, s: bytes):
        self.ser.write(s)

    def readLine(self) -> bytes:
        r = self.ser.read_until()
        return r

class InterfaceSocket:
    def __init__(self, ip, host):
        self.sock = socket.socket(socket.AF_INET, socket.SOCK_STREAM)
        self.sock.connect((ip, host))
        self.sock.settimeout(5)
        self.sockFile = self.sock.makefile(mode='rb')

    def write(self, s: bytes):
        self.sock.sendall(s)

    def readLine(self) -> bytes:
        r = self.sockFile.readline()
        return r

    def close():
        self.sockFile.close()
        self.sock.close()


class Update:
    chunkSize = 8192
    loopbackEnable = False       # set to True if the firmware has the debug line to print what was received

    def __init__(self):
        self.log = logging.getLogger('updater')
        self.interf = None

    def connectUart(self, port):
        self.interf = InterfaceSer(port)

    def connectSocket(self, ip, port):
        self.interf = InterfaceSocket(ip, port)

    def checkPing(self):
        self._writeSer('ping')
        r = self._readLine()
        if r != 'pong!':
            return False
        return True

    def setUartBaud(self, newBaud: int):
        self._writeSerAck(f'set uartBaud {newBaud:d}')
        self.interf.ser.flush()
        self.interf.ser.baudrate = newBaud
        # check for ping again, fail if not
        return self.checkPing()

    def setTimeMode(self, newMode: int):
        self._writeSerAck(f'set mode {newMode:s}')

    def reset(self):
        self._writeSer('reboot')

    def debugCancelLastUpdate(self):
        self.interf.write(b"\x00"*self.chunkSize)
        self._writeSerAck("update cancel")

    def update(self, file: Path):
        if not os.path.isfile(file):
            self.log.warning("file given is not a file")
            return False

        f = open(file, 'rb')
        try:
            binLen = os.path.getsize(file)

            # in case we had a previous on-going firmware update
            self._writeSerAck("update cancel")

            stat = self._writeSerAck(f"update begin {binLen:d}")
            if not stat:
                self.log.warning("unable to init update")
                return False

            while binLen > 0:
                toSend = min(self.chunkSize, binLen)

                stat = self._writeSerAck(f"update cont {toSend:d}")
                if not stat:
                    self.log.warning("unable to continue update")
                    return False
                # now we send the raw bytes
                self.interf.write(f.read(toSend))
                _ = self.interf.readLine()
                stat = self._waitForAck()
                if not stat:
                    self.log.warning("unable to continue update")
                    return False

                binLen -= toSend

            stat = self._writeSerAck(f"update end")
            if not stat:
                self.log.warning("unable to finish update")
                return False

            return True
        finally:
            f.close()

    def _writeSerAck(self, s: str):
        self._writeSer(s)
        return self._waitForAck()

    def _waitForAck(self):
        r = self._readLine()
        if r != 'ok':
            self.log.warning(f"did not return ok: {r}")
            return False
        return True

    def _writeSer(self, s: str):
        self.log.debug(f"-> {s}")
        self.interf.write(s.encode()+b'\n')

    def _readLine(self) -> str:
        if self.loopbackEnable:
            _ = self.interf.readLine()
        r = self.interf.readLine()
        r = r.decode().strip()
        self.log.debug(f"<- {r}")
        return r


def main():
    parser = argparse.ArgumentParser()
    parser.add_argument("file", type=Path, help="path to firmware file")
    parser.add_argument("serIp", type=str, help="serial port or ip")
    args = parser.parse_args()

    u = Update()

    if ':' in args.serIp:
        ip, port = args.serIp.split(':')
        port = int(port)
        u.connectSocket(ip, port)
        isUart = False
    else:
        u.connectUart(args.serIp)
        isUart = True

    # u.debugCancelLastUpdate()
    if not u.checkPing():
        print("Device did not repond with pong!")
        return
    # when updating, presumably the ISR shuts off during flash writting, causes the tubes flash a bit
    #   so better to turn the display off when updating
    u.setTimeMode('off')

    # todo: no worky with firmware. probably due to arduino overhead?
    # if isUart:
        # u.setUartBaud(460800)

    stat = u.update(args.file)
    if not stat:
        print("Unable to update firmware")
    else:
        u.reset()


if __name__ == "__main__":
    logging.basicConfig(level=logging.DEBUG)

    main()

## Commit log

2025-08-24 Initial Commit, added PCB files to tag and lock in
    [E-Calcs.ods, E1041 Rev 1 BOM.csv, E1041.kicad_pcb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]
2025-08-25 Added CAD stuff
    [Assy.FCStd, C1045.FCStd, C1046.FCStd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]
2025-09-16 Modified the case a bit
    [C1046.FCStd]
2025-09-20 c1047 rev 3
    [C1047.FCStd]
2025-11-09 new model
    [C1048.FCStd]
2026-01-05 Updated BOM, and errata for typo
    [E1041 Rev 1 BOM.csv]
2026-01-05 Updated for dowel pin...I think
    [C1046.FCStd]
2026-01-05 Added 'Part Number' in schematic, no design change
    [E1041.kicad_sch, ethernet.kicad_sch, ledDriver.kicad_sch]
2026-07-30 Some CAD modifications, commiting later so unsure exactly what
    [Assy.FCStd, C1045.FCStd, C1046.FCStd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]
2026-07-30 Firmware changes, see git log for more info
    Fixed build issue with zones.h
    Added 6th segment, updated so seconds are shown
    added command to change UART baud rate
    in firmware uploader script, added option if the firmware has loopback enabled for debugging purposes
    [F1044.ino, common.h, upload.py]
2026-07-30 Added my todo list for future pcb revision
2026-08-03 Moved project to PlatformIO Fixed updating and baud rate Refractor (finally possible in VSCode)
    [F1044.ino, common.h, upload.py]
2026-08-10 started work on a Modbus server Renamed the main firmware to a cpp file Fixed some issue with updater nice ascii art probably other changes I forgot about :)
    [F1044.cpp, common.h, upload.py]
2026-08-10 Fixed esp32 platform version. Updated docs
